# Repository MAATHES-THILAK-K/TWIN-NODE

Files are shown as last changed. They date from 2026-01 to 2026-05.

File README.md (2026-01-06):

## 📌 Project Overview

**TWIN-NODE** is a **two-node, ultra-low-power water level monitoring system** for overhead tanks.
It uses **ESP-NOW wireless communication**, requires **no internet**, and is optimized for **solar-powered outdoor operation**.

This project is **designed for manufacturable PCBs**, with all components chosen for reliability and low power.

---

## 🧩 System Architecture

| Node | Description |
| --- | --- |
| **NODE-1 (Outdoor Sensor Node)** | Measures water level using a waterproof ultrasonic sensor and transmits data wirelessly |
| **NODE-2 (Indoor Display Node)** | Receives water level data and alerts the user using LEDs and a buzzer |

---

## 🔧 NODE-1 – Outdoor Sensor Node

| Feature | Description |
| --- | --- |
| Controller | ESP-12F (ESP8266) |
| Sensor | SR04M / JSN-SR04T Waterproof Ultrasonic /HCSRO4|
| Power Source  | 18650 Li-ion Battery |
| Charging | Solar Panel + TP4056 |
| Regulation | RT9080-3.3 V LDO |
| Communication | ESP-NOW |
| Power Saving  | Deep Sleep + GPIO-controlled sensor power |
| Installation  | Weatherproof Enclosure |

---

## 🔋 Low-Power Design

| Technique | Purpose |
| --- | --- |
| Deep Sleep Mode | Minimizes battery consumption |
| GPIO-controlled Sensor Power | Cuts sensor standby current |
| LDO with low quiescent current | Efficient voltage regulation |
| ESP-NOW | Low-energy wireless communication |

---

## 📂 Repository Structure

| Folder | Purpose |
| --- | --- |
| `TWIN NODE V1.0/` | Stable, tested hardware revision |
| `TWIN NODE V2.0/` | Updated hardware revision (new features, improvements) |
| `Gerber/` | Manufacturing-ready files |
| `IMAGES/` | PCB renders and photos |
| `REPORT/` | ERC, DRC, design checks |
| `3D MODELS/` | Mechanical references |
| `LICENSE` | Open-source licensing information |
| `README.md` | Project overview and documentation |

---

## 🚀 Engineering Note

* Designed for **low-power operation**
* **Solar and battery-friendly**
* **Manufacturable PCB**
* Versioned structure makes it easy to track revisions

---

### 👤 Author

**MAATHES-THILAK-K (KMT)**
Embedded Systems | PCB Design | Robotics

---

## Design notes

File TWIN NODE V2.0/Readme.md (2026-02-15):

# TWIN NODE V2.0

### Low-Power Outdoor Water Level Sensor Node – Improved Design

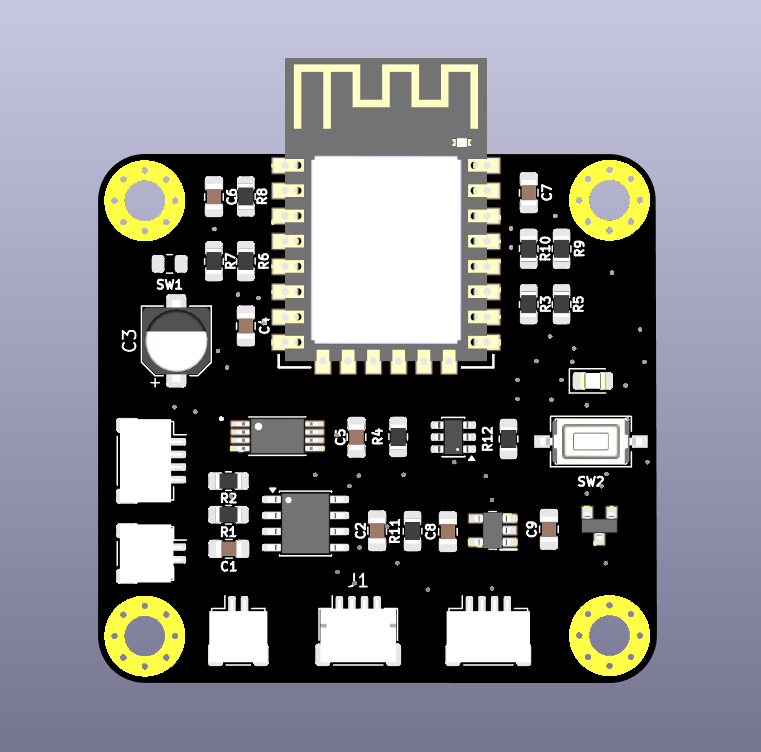
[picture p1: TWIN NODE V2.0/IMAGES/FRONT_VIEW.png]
TWIN NODE V2.0 Front View


---

## 📌 Overview

**TWIN NODE V2.0** is the **fabricated and tested hardware revision** of the low-power ESP-NOW water level monitoring system.
This version incorporates **real-world fabrication feedback**, improving reliability and simplifying the design for future revisions.

All components are sourced from [ROBU.IN](https://robu.in).

---

## ⚙️ Key Updates from V1.0

* **Mounting holes:** Increased from 3 to **4** for better casing support
* **I2C expanders:** Removed, no longer required
* **Programming & power connections:** Female headers replaced with **JST connectors**
* **Component placement:** Fully optimized for **aesthetic and practical routing**
* **PCB traces:** Increased width to support **longer interconnections**
* **PCB size:** ~45 × 45 mm
* **DRC & ERC:** Fully verified
* **Fabricated & powered ON successfully**

---

## 🛠️ Fabrication Feedback & Design Correction (Important)

During physical testing of the fabricated PCB, the following observation was made:

### ❌ Unnecessary Pull-Up Resistors Identified

* **GPIO0 (BOOT)** – 10 kΩ resistor **not required**
* **RST (RESET)** – 10 kΩ resistor **not required**

These resistors were found to be **redundant** and **can be safely removed** in future PCB revisions.

### ✅ Reason

* ESP8266 12K pull-ups are sufficient for:

  * Normal boot operation
  * Reliable reset behavior
* External 10 kΩ resistors on **GPIO0** and **RST**:

  * Do **not improve stability**
  * Increase component count unnecessarily
  * Slightly complicate routing and assembly

➡️ **Action for next revision:**
Remove the 10 kΩ pull-up resistors on **GPIO0 (BOOT)** and **RST**.

---

## 🔧 Design Notes

* Designed for **battery + solar operation**
* Optimized for **low power outdoor deployment**
* ESP-NOW based communication (no Wi-Fi AP dependency)
* Layout finalized with **manufacturability in mind**
* Suitable for **field deployment and enclosure mounting**

---

## 📦 Project Status

✔ PCB fabricated
✔ Power-up verified
✔ Boot & reset behavior validated
✔ Design improvement identified for next revision

---

### 👤 Author

**MAATHES-THILAK-K (KMT)**
Embedded Systems | PCB Design | Robotics

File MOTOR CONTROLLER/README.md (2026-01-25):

# ⚙️ TWIN-NODE – Motor Controller
## Overview

The **TWIN-NODE Motor Controller** is a compact wireless motor control module designed to work with the TWIN-NODE water level monitoring system.
It enables **remote ON/OFF control of a water pump** using **ESP-NOW**, without internet connectivity.

---
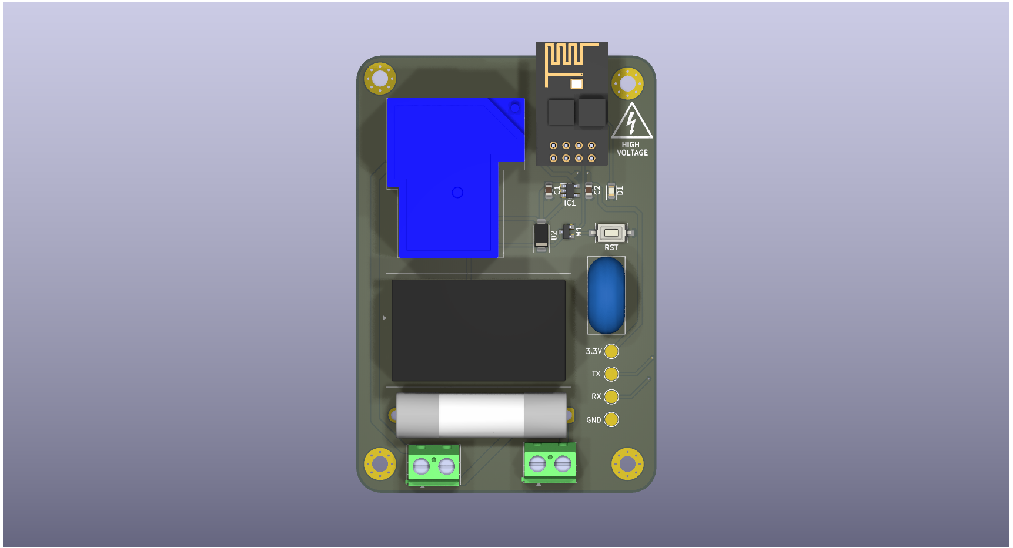
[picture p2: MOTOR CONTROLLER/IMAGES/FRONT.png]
Motor Controller PCB

---

## Key Features

* ESP-01 (ESP8266) based controller
* Wireless control using ESP-NOW
* Relay-based motor switching
* Electrical isolation between control and load
* Manufacturable PCB design

---

## Hardware Summary

| Item | Description |
| --- | --- |
| MCU | ESP-01 (ESP8266) |
| Communication | ESP-NOW |
| Motor Control | Relay |
| PCB Files | KiCad + Gerber |
| Application | Water pump control |

---

## Repository Contents

* Gerber files for manufacturing
* KiCad schematic & PCB
* 3D models and images
* Design reports (ERC/DRC)

---

## Author

**MAATHES-THILAK-K (KMT)**
Embedded Systems | PCB Design | Robotics

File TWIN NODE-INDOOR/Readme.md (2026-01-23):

# TWIN-NODE – Indoor Node

## Overview

The **Indoor Node** is a **battery-powered, ultra-low-power receiver and alert unit** for the TWIN-NODE water level monitoring system.
It receives water level data from the outdoor sensor node using **ESP-NOW** and provides **local LED and buzzer alerts**, without internet or Wi-Fi infrastructure.

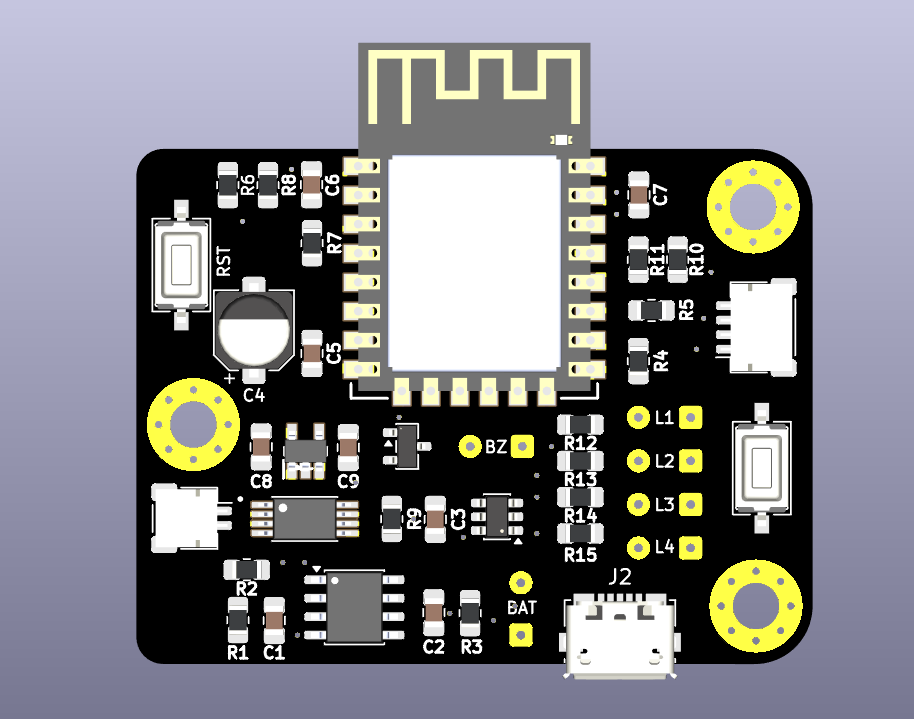
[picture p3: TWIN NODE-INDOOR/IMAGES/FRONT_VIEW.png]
Indoor Node Front View


---

## Key Features

* ESP-NOW wireless communication
* Battery-powered operation
* Ultra-low-power design
* LED level indication
* Buzzer alert for critical levels
* No internet, no router, no cloud

---

## Hardware Summary

| Item | Specification |
| --- | --- |
| MCU | ESP-12F (ESP8266) |
| Communication | ESP-NOW |
| Indicators | LEDs |
| Alert | Buzzer |
| Power Source  | Battery |
| Design Tool | KiCad |

---

## Power Design

* Deep sleep enabled
* Wake on ESP-NOW receive
* Minimal standby current
* Optimized for long-term battery life

---

## Repository Contents

| Path | Description |
| --- | --- |
| `GERBER/` | Manufacturing files |
| `IMAGES/` | PCB images |
| `REPORT/` | ERC / DRC |
| `3D MODELS/` | Mechanical models |
| `TWIN_NODE2.kicad_*` | Schematic & PCB |

---

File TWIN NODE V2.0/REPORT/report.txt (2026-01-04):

Plotted to '/home/kmt-universe/Desktop/TWIN_NODE/Gerber/TWIN_NODE-F_Cu.gbr'.
Plotted to '/home/kmt-universe/Desktop/TWIN_NODE/Gerber/TWIN_NODE-B_Cu.gbr'.
Plotted to '/home/kmt-universe/Desktop/TWIN_NODE/Gerber/TWIN_NODE-F_Paste.gbr'.
Plotted to '/home/kmt-universe/Desktop/TWIN_NODE/Gerber/TWIN_NODE-B_Paste.gbr'.
Plotted to '/home/kmt-universe/Desktop/TWIN_NODE/Gerber/TWIN_NODE-F_Silkscreen.gbr'.
Plotted to '/home/kmt-universe/Desktop/TWIN_NODE/Gerber/TWIN_NODE-B_Silkscreen.gbr'.
Plotted to '/home/kmt-universe/Desktop/TWIN_NODE/Gerber/TWIN_NODE-F_Mask.gbr'.
Plotted to '/home/kmt-universe/Desktop/TWIN_NODE/Gerber/TWIN_NODE-B_Mask.gbr'.
Plotted to '/home/kmt-universe/Desktop/TWIN_NODE/Gerber/TWIN_NODE-Edge_Cuts.gbr'.
Created Gerber job file '/home/kmt-universe/Desktop/TWIN_NODE/Gerber/TWIN_NODE-job.gbrjob'.
Info: Done.
Info: Done.

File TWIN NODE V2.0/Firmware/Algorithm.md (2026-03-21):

# 🌊 Smart Water Tank Monitoring System (ESP8266 + ESP-NOW)

## 📌 Overview

This project implements an **ultra-low-power outdoor water level monitoring system** using an ESP-12F (ESP8266) and ultrasonic sensing. The system communicates with an indoor node via **ESP-NOW**, ensuring efficient, connectionless data transfer.

The design prioritizes:

* 🔋 Ultra-low power consumption (solar + Li-ion)
* ⚡ Event-driven communication
* 📡 Reliable short-range wireless communication
* 🧠 Intelligent state-based operation

---

## 🏗️ System Architecture

### 🌿 Outdoor Node (Sensor Unit)

* ESP-12F (ESP8266)
* Ultrasonic sensor (power-gated via MOSFET)
* Solar + Li-ion powered
* Operates mostly in **deep sleep**

### 🏠 Indoor Node (User Interface)

* ESP8266 (ESP-NOW receiver)
* 4 LEDs (water level indication)
* Buzzer (alerts)
* Optional mobile connectivity

---

## 🔄 System Workflow

### 🌿 Outdoor Node (State Machine)

---

### 🔹 LOW POWER MODE

```text
[Deep Sleep]

↓ Wake (every 5 minutes)

Power ON ultrasonic
Wait 50 ms stabilization

Take 3 readings → Apply median filter
Power OFF ultrasonic

IF |current_distance - last_sent| < delta_threshold:
    → Return to deep sleep (5 min)

ELSE:
    Send data via ESP-NOW

    Wait 100 ms for ACK

    IF ACK received:
        last_sent = current_distance
        Reset failure counter
        Switch to ACTIVE MODE

    ELSE:
        Retry (max 2 times)
        → Return to deep sleep (5 min)
```

---

### ⚡ ACTIVE MODE

```text
Wake every 1–2 minutes

Measure distance (filtered)

IF |current_distance - last_sent| ≥ delta_threshold:
    Send data → Wait for ACK

    IF ACK received:
        Update last_sent
        Reset failure counter

    ELSE:
        Increment failure counter

IF failure counter ≥ 3:
    Switch to LOW POWER MODE

Return to deep sleep (1–2 min)
```

---

## 🏠 Indoor Node Logic

```text
Always listening (ESP-NOW)

On receiving data:
    Send ACK immediately
    Store received distance
    Update LED indicators
    Trigger buzzer (only if critical)

Optional:
    Send data to mobile application
```

---

## 📊 Water Level Indication

Water level is computed as:

```text
Level (%) = (Tank Height - Measured Distance) / Tank Height
```

| Level (%) | Indicator |
| --- | --- |
| 0–25% | LED 1 |
| 25–50% | LED 2 |
| 50–75% | LED 3 |
| 75–100% | LED 4 |

---

## 🔊 Buzzer Logic

The buzzer is triggered only when:

* ✅ Tank becomes FULL
* ⚠️ Sudden drop in water level (optional)

Avoid continuous alerts to improve user experience.

---

## 🧪 Sensor Filtering

To improve accuracy in outdoor conditions:

* Take **3 consecutive readings**
* Apply **median filtering**
* Reject noise and outliers

---

## 📡 Communication Protocol

### Data Packet (Outdoor → Indoor)

```c
struct DataPacket {
  uint16_t distance;
  uint8_t state;
  uint8_t battery; // optional
};
```

### ACK Packet (Indoor → Outdoor)

```c
struct AckPacket {
  uint8_t status; // 1 = received
};
```

---

## ⚡ Power Optimization Techniques

* Deep sleep between operations
* Sensor power gating via MOSFET
* Short ESP-NOW transmission bursts
* No continuous listening on outdoor node
* Event-driven communication

---

## 🔋 Power Profile

| Mode | Current Consumption |
| --- | --- |
| Deep Sleep | ~20–70 µA |
| Active | ~120 mA (short burst) |

---

## 🚨 Fail-Safe Mechanisms

| Condition | System Behavior |
| --- | --- |
| Indoor node OFF | Retry → fallback to LOW POWER MODE |
| Communication failure | Retry (max 2 times) |
| No ACK in ACTIVE MODE | Return to LOW POWER MODE |
| Sensor noise | Median filtering applied |

---

## 🚀 Future Improvements

* 🔋 Battery-aware adaptive sleep intervals
* 📶 Mobile app integration
* ☁️ Cloud logging
* 📉 Data history visualization
* 🧠 Predictive water usage analytics

---

## 🎯 Key Design Goals Achieved

* ✅ Ultra-low power outdoor node
* ✅ Reliable wireless communication
* ✅ Event-driven updates
* ✅ Scalable architecture
* ✅ User-friendly indoor interface

---

## 🙌 Author

Developed by **MAATHES THILAK K**
IInd year (4th semester)
March 22 2.22am 
---

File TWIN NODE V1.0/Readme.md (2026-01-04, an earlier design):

# TWIN NODE V1.0

### Low-Power Outdoor Water Level Sensor Node

---

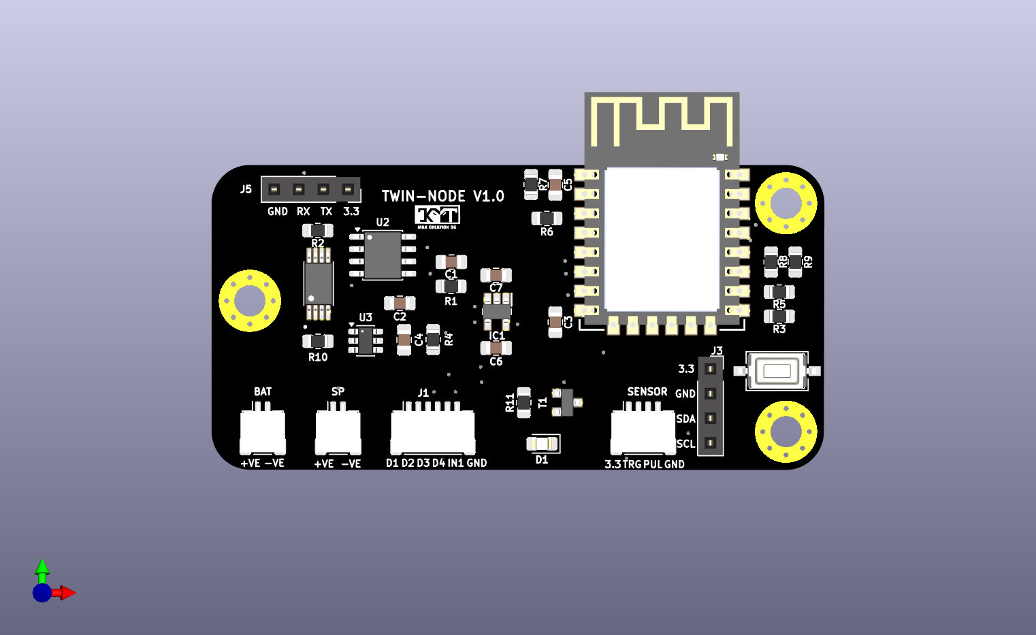
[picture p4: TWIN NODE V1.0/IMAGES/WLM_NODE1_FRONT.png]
TWIN NODE V1.0 Front View


## 📌 Overview

**TWIN NODE V1.0** is the **first hardware version** of a low-power, ESP-NOW-based water level monitoring system.
It is **designed for learning and prototyping**, with all components sourced from [ROBU.IN](https://robu.in).

---

## ⚙️ Features

* **ESP-12F (ESP8266)** controller
* **Waterproof ultrasonic sensor** for water level measurement
* **Female headers** for programming and I2C expanders
* **SCL & SDA I2C lines** accessible for future expansion
* **Three mounting holes** for secure installation
* PCB size: **~65 × 35 mm**
* Component placement: Functional but **aesthetic may be rough (good for first-time design)**
* **DRC & ERC verified**, footprints selected for manufacturability

---

## 🔧 Notes

* Ready for **battery + solar operation**
* Ideal for testing ESP-NOW wireless communication
* Serves as **foundation for TWIN NODE V2.0**

---

### 👤 Author

**MAATHES-THILAK-K (KMT)**
Embedded Systems | PCB Design | Robotics

---

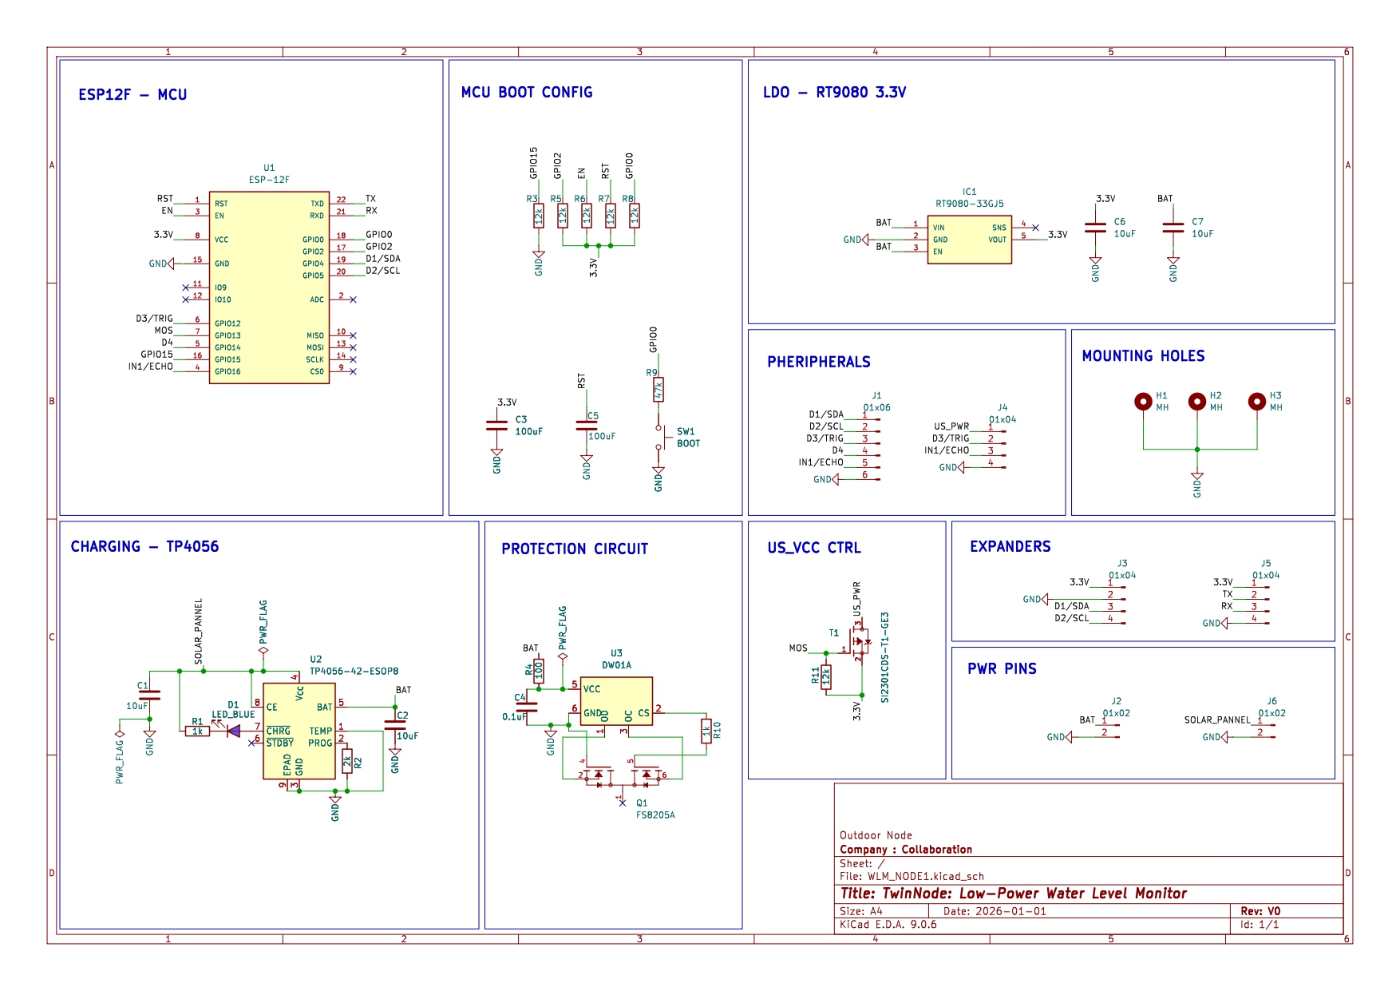
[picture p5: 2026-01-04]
TWIN NODE V2.0/IMAGES/TWIN_NODE_page-0001.jpg

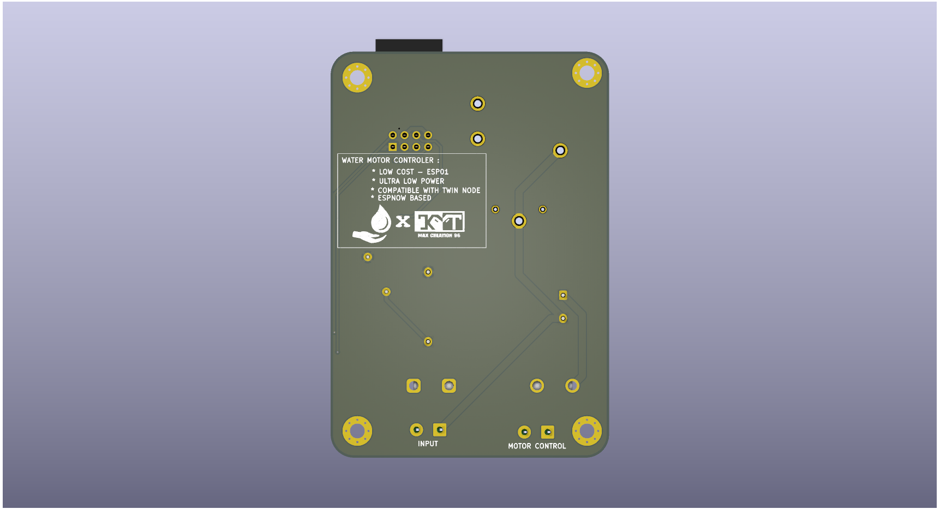
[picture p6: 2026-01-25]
MOTOR CONTROLLER/IMAGES/BACK.png

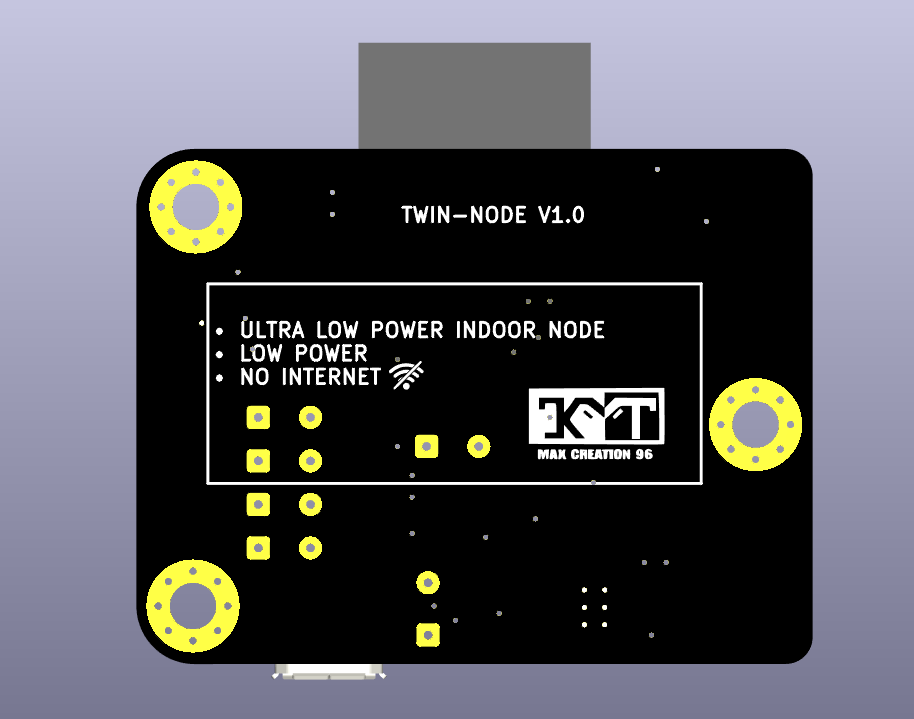
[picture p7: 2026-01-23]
TWIN NODE-INDOOR/IMAGES/BACK_VIEW.png

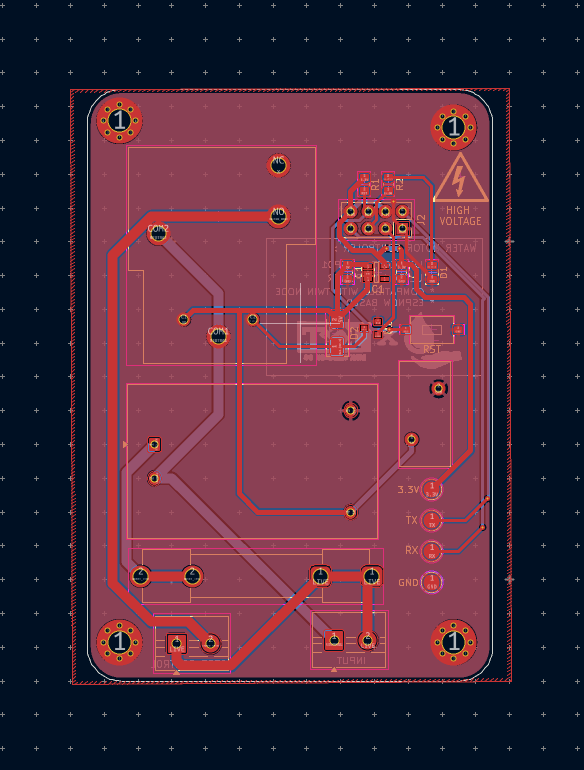
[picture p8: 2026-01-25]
MOTOR CONTROLLER/IMAGES/LAYOUT_1.png

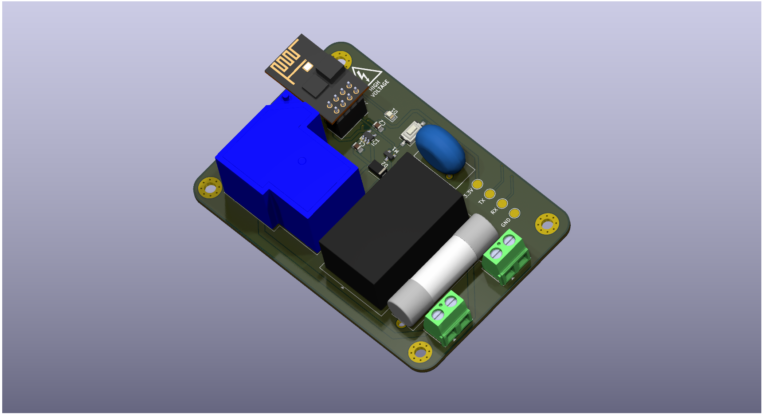
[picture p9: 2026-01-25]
MOTOR CONTROLLER/IMAGES/ISOMETRIC.png

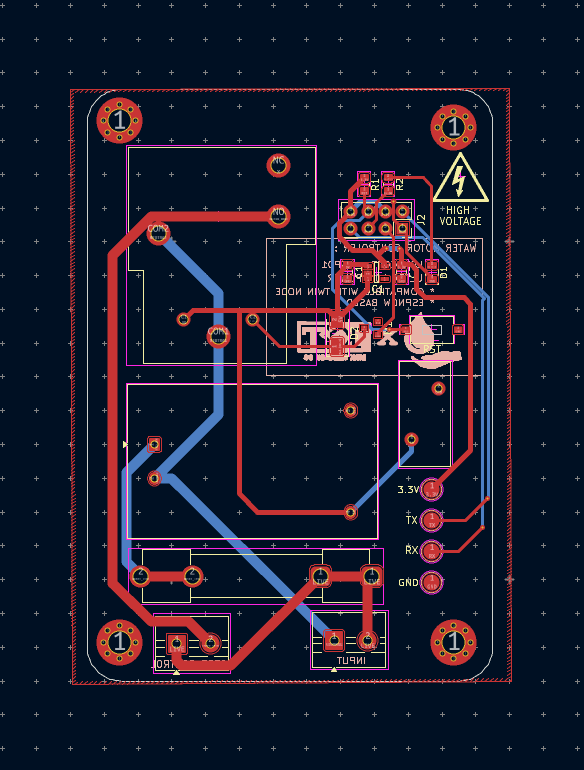
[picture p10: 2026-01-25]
MOTOR CONTROLLER/IMAGES/LAYOUT_2.png

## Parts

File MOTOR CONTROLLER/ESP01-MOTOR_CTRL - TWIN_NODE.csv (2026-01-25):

Reference | Qty | Value | DNP | Exclude from BOM | Exclude from Board | Footprint | Datasheet
C1,C2 | 2 | 10uF |  |  |  | Capacitor_SMD:C_0805_2012Metric_Pad1.18x1.45mm_HandSolder | ~
D1 | 1 | LED |  |  |  | LED_SMD:LED_0805_2012Metric_Pad1.15x1.40mm_HandSolder | ~
D2 | 1 | SS12 |  |  |  | Diode_SMD:D_SMA | https://www.vishay.com/docs/88746/ss12.pdf
F1 | 1 | 250V@500mA |  |  |  | Fuse:Fuseholder_Clip-6.3x32mm_Littelfuse_102_122_Inline_P34.21x7.62mm_D1.98mm_Horizontal | ~
H1,H2,H3,H4 | 4 | MH |  | Excluded from BOM |  | MountingHole:MountingHole_3.2mm_M3_Pad_Via | ~
IC1 | 1 | RT9080-33GJ5 |  |  |  | RT9080-33GJ5:SOT94P280X100-5N
J1 | 1 | MOTOR |  |  |  | TerminalBlock:TerminalBlock_MaiXu_MX126-5.0-02P_1x02_P5.00mm | ~
J2 | 1 | 02X04 |  |  |  | Connector_PinSocket_2.54mm:PinSocket_2x04_P2.54mm_Vertical | ~
J3 | 1 | INPUT |  |  |  | TerminalBlock:TerminalBlock_MaiXu_MX126-5.0-02P_1x02_P5.00mm | ~
K1 | 1 | SLA-5VDC-SL-C |  |  |  | SLA-12VDC-SL-C:RELAY_SLA-12VDC-SL-C
M1 | 1 | SI2300 |  |  |  | SI2301CDS-T1-GE3:SOT-23
PS1 | 1 | HLK-PM01 |  |  |  | Converter_ACDC:Converter_ACDC_Hi-Link_HLK-PMxx | https://h.hlktech.com/download/ACDC%E7%94%B5%E6%BA%90%E6%A8%A1%E5%9D%973W%E7%B3%BB%E5%88%97/1/%E6%B5%B7%E5%87%8C%E7%A7%913W%E7%B3%BB%E5%88%97%E7%94%B5%E6%BA%9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
R1 | 1 | 10K |  |  |  | Resistor_SMD:R_0805_2012Metric_Pad1.20x1.40mm_HandSolder | ~
R2 | 1 | 1K |  |  |  | Resistor_SMD:R_0805_2012Metric_Pad1.20x1.40mm_HandSolder | ~
RV1 | 1 | 275V-14D |  |  |  | Varistor:RV_Disc_D15.5mm_W7.5mm_P7.5mm | ~
SW1 | 1 | SW_Push |  |  |  | Button_Switch_SMD:SW_Tactile_SPST_NO_Straight_CK_PTS636Sx25SMTRLFS | ~
TP1,TP2,TP3,TP4 | 4 | TestPoint |  |  |  | TestPoint:TestPoint_Pad_D2.5mm | ~

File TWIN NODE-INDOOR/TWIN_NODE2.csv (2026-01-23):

Reference | Qty | Value | DNP | Exclude from BOM | Exclude from Board | Footprint | Datasheet
C1,C2,C5,C8,C9 | 5 | 10uF |  |  |  | Capacitor_SMD:C_0805_2012Metric_Pad1.18x1.45mm_HandSolder | ~
C3 | 1 | 0.1uF |  |  |  | Capacitor_SMD:C_0805_2012Metric_Pad1.18x1.45mm_HandSolder | ~
C4 | 1 | 100uF |  |  |  | Capacitor_SMD:CP_Elec_5x5.3 | ~
C6,C7 | 2 | 100nF |  |  |  | Capacitor_SMD:C_0805_2012Metric_Pad1.18x1.45mm_HandSolder | ~
D1 | 1 | LED_BLUE |  |  |  | Connector_Wire:SolderWire-0.1sqmm_1x02_P3.6mm_D0.4mm_OD1mm | ~
D2,D3,D4,D5 | 4 | LED |  |  |  | Connector_Wire:SolderWire-0.1sqmm_1x02_P3.6mm_D0.4mm_OD1mm | ~
H1,H2,H3 | 3 | MH |  | Excluded from BOM |  | MountingHole:MountingHole_3.2mm_M3_Pad_Via | ~
IC1 | 1 | RT9080-33GJ5 |  |  |  | RT9080-33GJ5:SOT94P280X100-5N
J1 | 1 | 01x02 |  |  |  | Connector_Wire:SolderWire-0.1sqmm_1x02_P3.6mm_D0.4mm_OD1mm | ~
J2 | 1 | USB_B_Micro |  |  |  | Connector_USB:USB_Micro-B_Molex_47346-0001 | ~
J3 | 1 | 01x02 |  |  |  | Connector_JST:JST_SH_SM02B-SRSS-TB_1x02-1MP_P1.00mm_Horizontal | ~
J4 | 1 | 01x04 |  |  |  | Connector_JST:JST_SH_SM04B-SRSS-TB_1x04-1MP_P1.00mm_Horizontal | ~
Q1 | 1 | FS8205A |  |  |  | FS8205A:SOP65P640X120-8N
Q2 | 1 | BSS138 |  |  |  | Package_TO_SOT_SMD:SOT-23 | https://www.onsemi.com/pub/Collateral/BSS138-D.PDF
R1,R9 | 2 | 1k |  |  |  | Resistor_SMD:R_0805_2012Metric_Pad1.20x1.40mm_HandSolder | ~
R2 | 1 | 2k |  |  |  | Resistor_SMD:R_0805_2012Metric_Pad1.20x1.40mm_HandSolder | ~
R3 | 1 | 100 |  |  |  | Resistor_SMD:R_0805_2012Metric_Pad1.20x1.40mm_HandSolder | ~
R4,R5,R7,R8,R10 | 5 | 12k |  |  |  | Resistor_SMD:R_0805_2012Metric_Pad1.20x1.40mm_HandSolder | ~
R6,R11 | 2 | 10k |  |  |  | Resistor_SMD:R_0805_2012Metric_Pad1.20x1.40mm_HandSolder | ~
R12,R13,R14,R15 | 4 | 330 |  |  |  | Resistor_SMD:R_0805_2012Metric_Pad1.20x1.40mm_HandSolder | ~
SW1 | 1 | RST |  |  |  | Button_Switch_SMD:SW_Tactile_SPST_NO_Straight_CK_PTS636Sx25SMTRLFS | ~
SW2 | 1 | BOOT |  |  |  | Button_Switch_SMD:SW_Tactile_SPST_NO_Straight_CK_PTS636Sx25SMTRLFS | ~
U1 | 1 | ESP-12F |  |  |  | ESP-12F:ESP-12F
U2 | 1 | TP4056-42-ESOP8 |  |  |  | Package_SO:SOIC-8-1EP_3.9x4.9mm_P1.27mm_EP2.41x3.3mm_ThermalVias | https://www.lcsc.com/datasheet/lcsc_datasheet_2410121619_TOPPOWER-Nanjing-Extension-Microelectronics-TP4056-42-ESOP8_C16581.pdf
U3 | 1 | DW01A |  |  |  | Package_TO_SOT_SMD:SOT-23-6 | https://hmsemi.com/downfile/DW01A.PDF

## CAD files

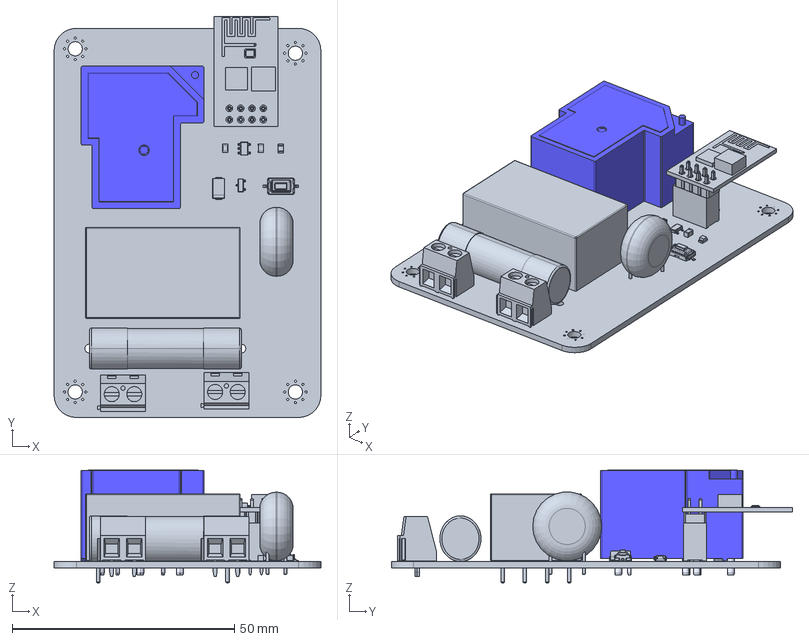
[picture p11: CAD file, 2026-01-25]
MOTOR CONTROLLER/3D MODEL/ESP01-MOTOR_CTRL - TWIN_NODE.step
60.0 x 90.2 x 25.3 mm
SLA-12VDC-SL-C_SLA-12VDC-SL-C
SI2300
D_SMA
R_0805_2012Metric x 2
282837-2--3DModel-STEP-269445 x 2
BUSSMANN PV Fuse 10x38mm
RV_Disc_D15.5mm_W7.5mm_P7.5mm
LED_0805_2012Metric
PinSocket_2x04_P2.54mm_Vertical
ESP-01
Converter_ACDC_Hi-Link_HLK-PMxx
SW_Tactile_SPST_NO_Straight_CK_PTS636Sx25SMTRLFS
C_0805_2012Metric x 2
RT9080-33GJ5
ESP01-MOTOR_CTRL - TWIN_NODE_PCB

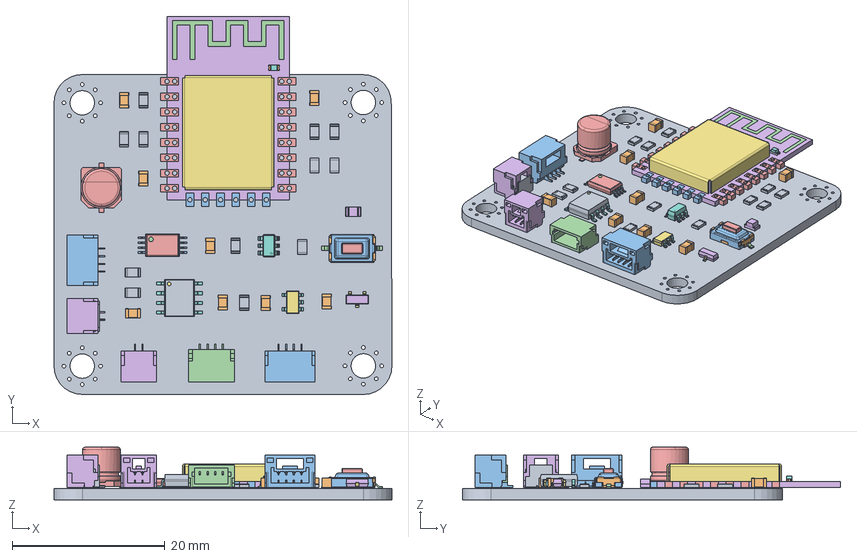
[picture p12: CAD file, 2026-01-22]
TWIN NODE V2.0/3D MODELS/TWIN_NODE.step
44.2 x 49.5 x 6.89 mm
R_0805_2012Metric x 12
C_0805_2012Metric x 8
FS8205A--3DModel-STEP-56544
JST_GH_SM02B-GHS-TB_1x02-1MP_P1.25mm_Horizontal x 2
TP4056
JST_GH_SM04B-GHS-TB_1x04-1MP_P1.25mm_Horizontal x 2
JST_SH_SM04B-SRSS-TB_1x04-1MP_P1.00mm_Horizontal
CP_Elec_5x5.3
LED_0805_2012Metric
ESP-12F
RT9080-33GJ5
JST_SH_SM02B-SRSS-TB_1x02-1MP_P1.00mm_Horizontal
SW_Tactile_SPST_NO_Straight_CK_PTS636Sx25SMTRLFS
SI2301CDS-T1-GE3
SOT-23-6
TWIN_NODE_PCB

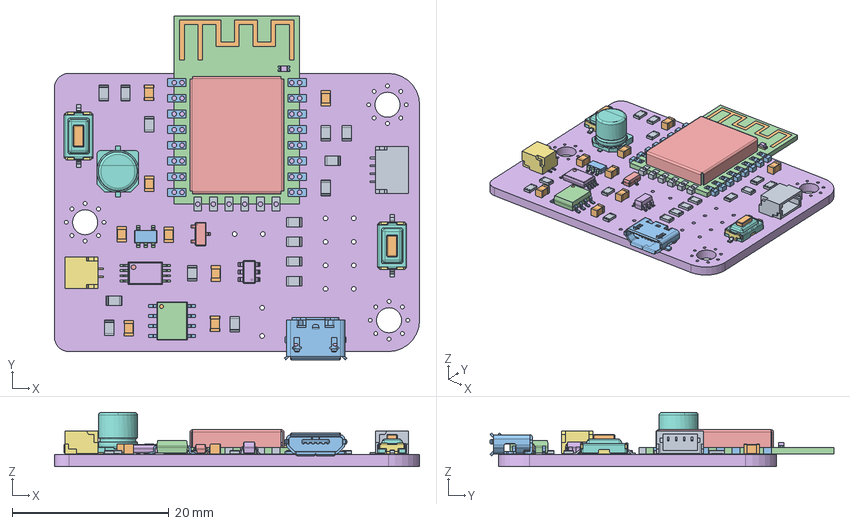
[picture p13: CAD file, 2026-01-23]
TWIN NODE-INDOOR/3D MODELS/TWIN_NODE2.step
46.6 x 43.9 x 6.89 mm
R_0805_2012Metric x 15
C_0805_2012Metric x 8
USB_Micro-B_Molex_47346-0001
FS8205A--3DModel-STEP-56544
SW_Tactile_SPST_NO_Straight_CK_PTS636Sx25SMTRLFS x 2
RT9080-33GJ5
ESP-12F
SOT-23
SOT-23-6
JST_SH_SM02B-SRSS-TB_1x02-1MP_P1.00mm_Horizontal
CP_Elec_5x5.3
JST_SH_SM04B-SRSS-TB_1x04-1MP_P1.00mm_Horizontal
TP4056
TWIN_NODE2_PCB

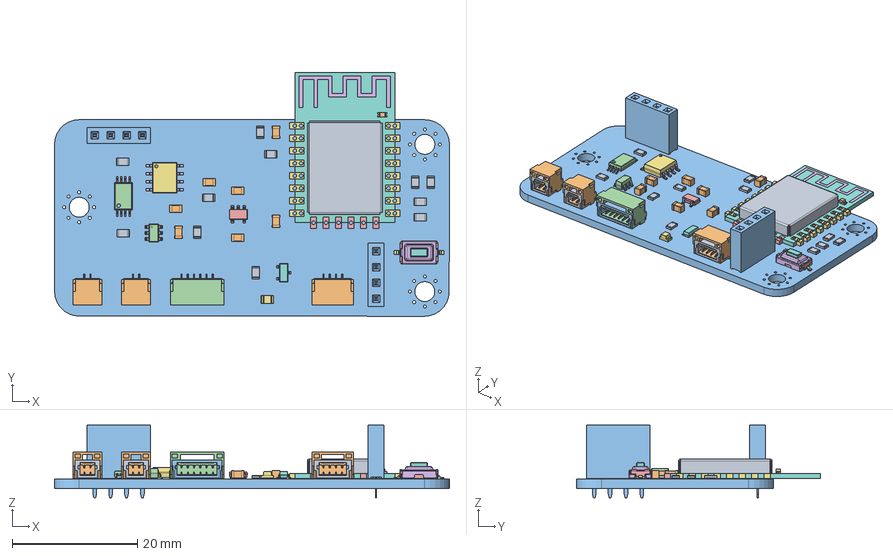
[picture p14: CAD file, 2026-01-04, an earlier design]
TWIN NODE V1.0/3D MODELS/WLM_NODE1.step
63.2 x 39.0 x 11.6 mm
R_0805_2012Metric x 11
C_0805_2012Metric x 7
JST_SH_SM06B-SRSS-TB_1x06-1MP_P1.00mm_Horizontal
JST_GH_SM06B-GHS-TB_1x06-1MP_P1.25mm_Horizontal
RT9080-33GJ5
LED_0805_2012Metric
SI2301CDS-T1-GE3
FS8205A--3DModel-STEP-56544
TP4056
JST_SH_SM02B-SRSS-TB_1x02-1MP_P1.00mm_Horizontal x 2
JST_GH_SM02B-GHS-TB_1x02-1MP_P1.25mm_Horizontal x 2
PinSocket_1x04_P2.54mm_Vertical x 2
SOT-23-6
SW_Tactile_SPST_NO_Straight_CK_PTS636Sx25SMTRLFS
ESP-12F
JST_SH_SM04B-SRSS-TB_1x04-1MP_P1.00mm_Horizontal
JST_GH_SM04B-GHS-TB_1x04-1MP_P1.25mm_Horizontal
WLM_NODE1_PCB

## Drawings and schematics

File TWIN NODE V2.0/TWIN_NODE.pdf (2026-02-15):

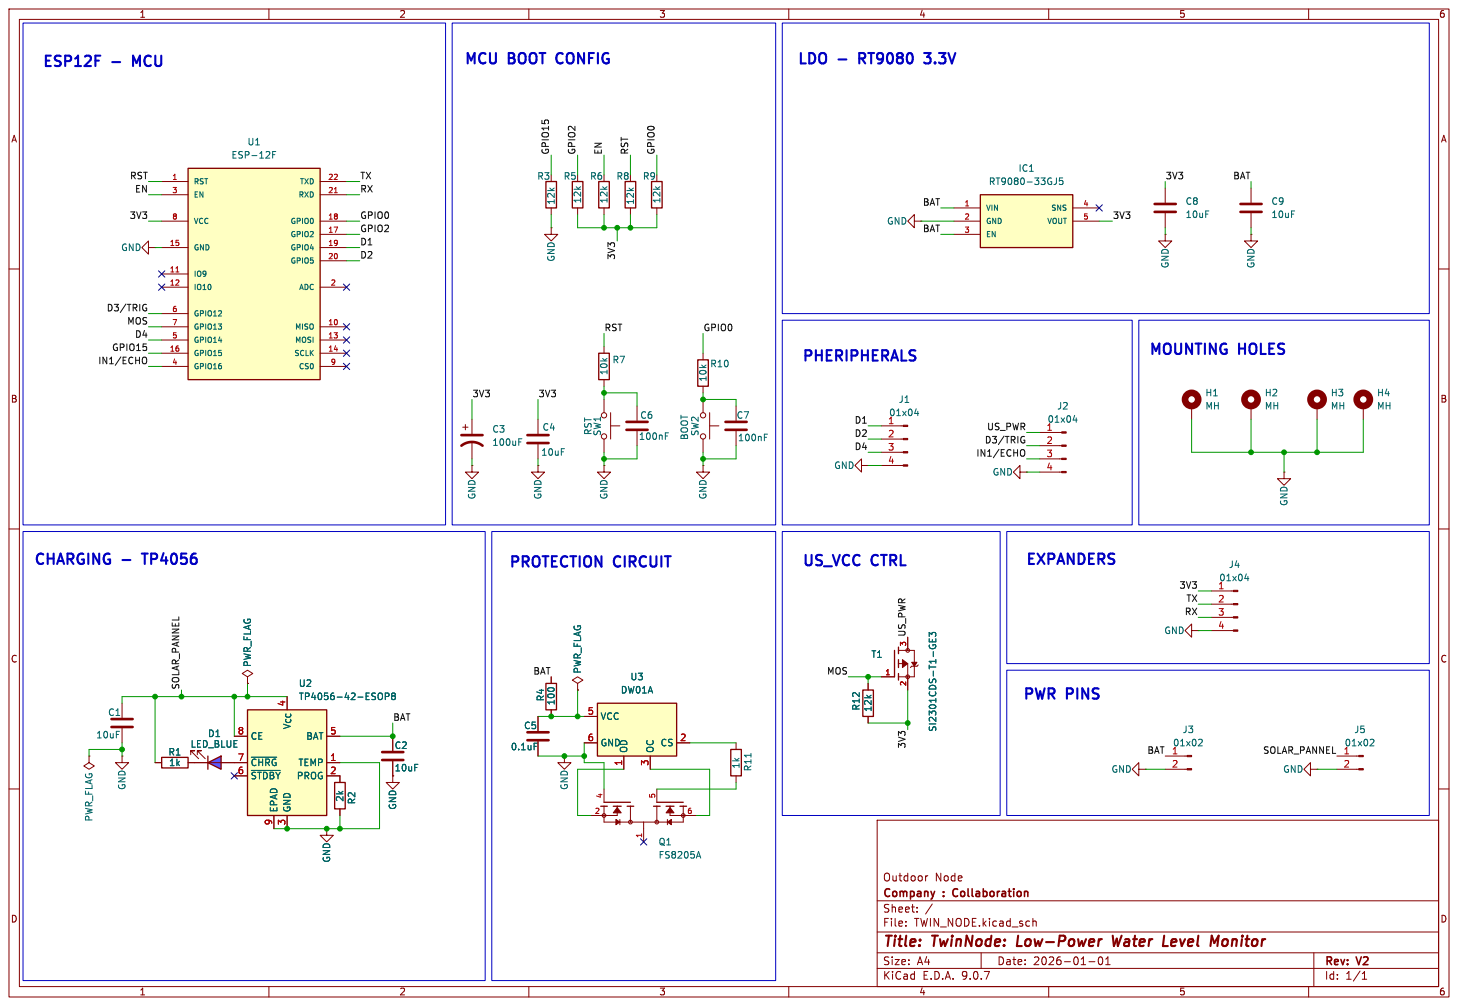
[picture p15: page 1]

3 BAT 5 TEMP 1 PROG 2 U2 TP4056-42-ESOP8 GND

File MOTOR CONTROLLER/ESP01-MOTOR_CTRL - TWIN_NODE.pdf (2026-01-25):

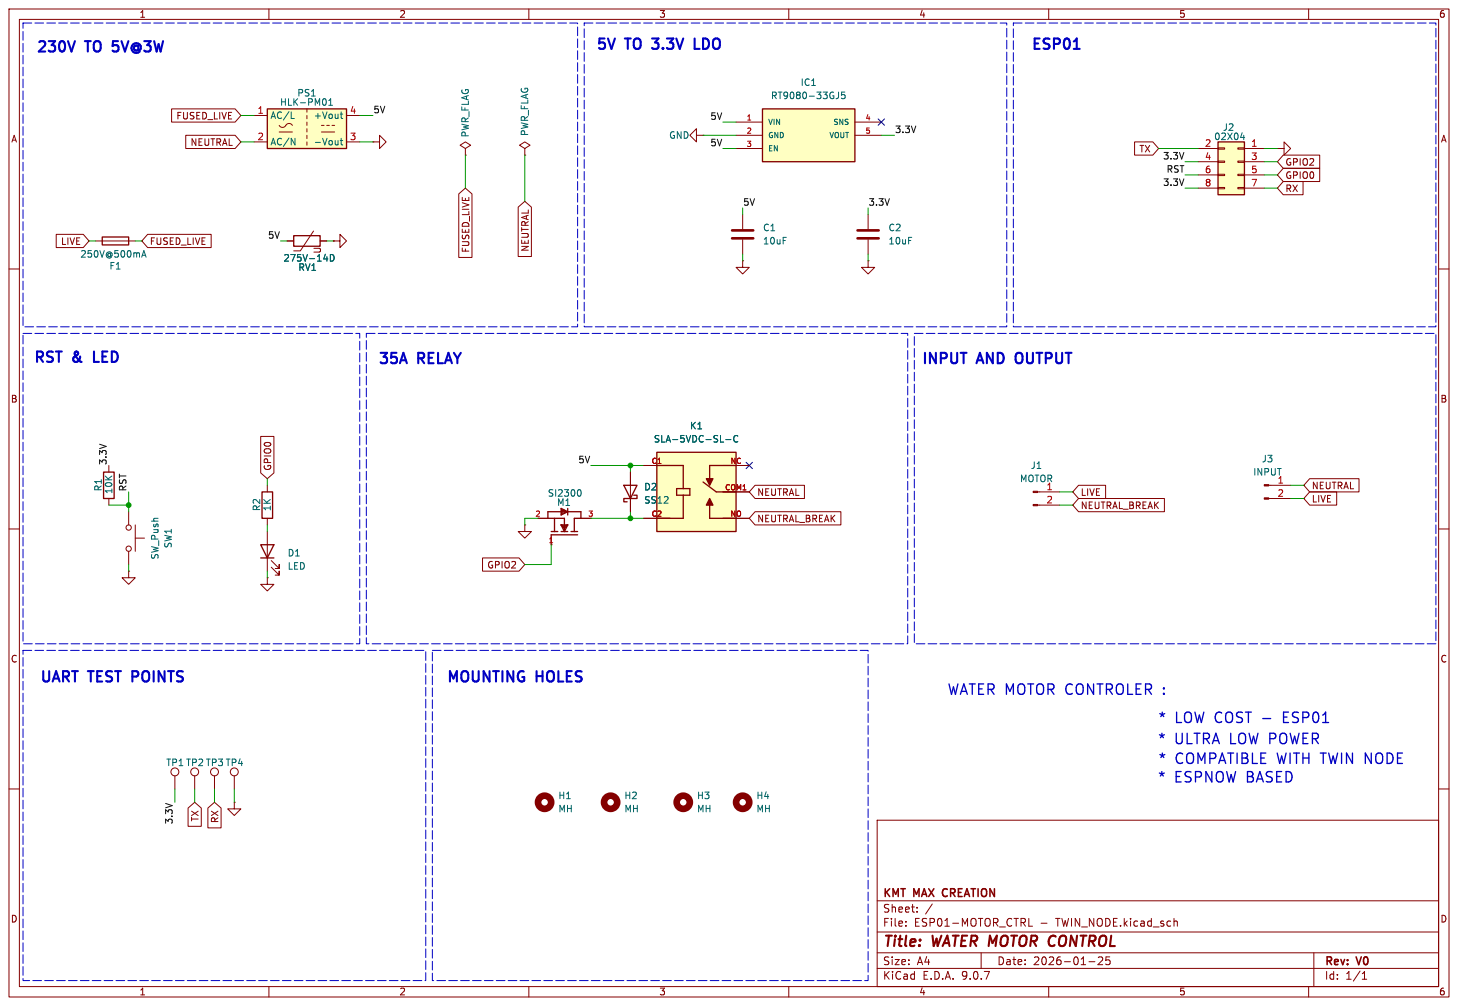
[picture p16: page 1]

Id: 1/1 Title: WATER MOTOR CONTROL

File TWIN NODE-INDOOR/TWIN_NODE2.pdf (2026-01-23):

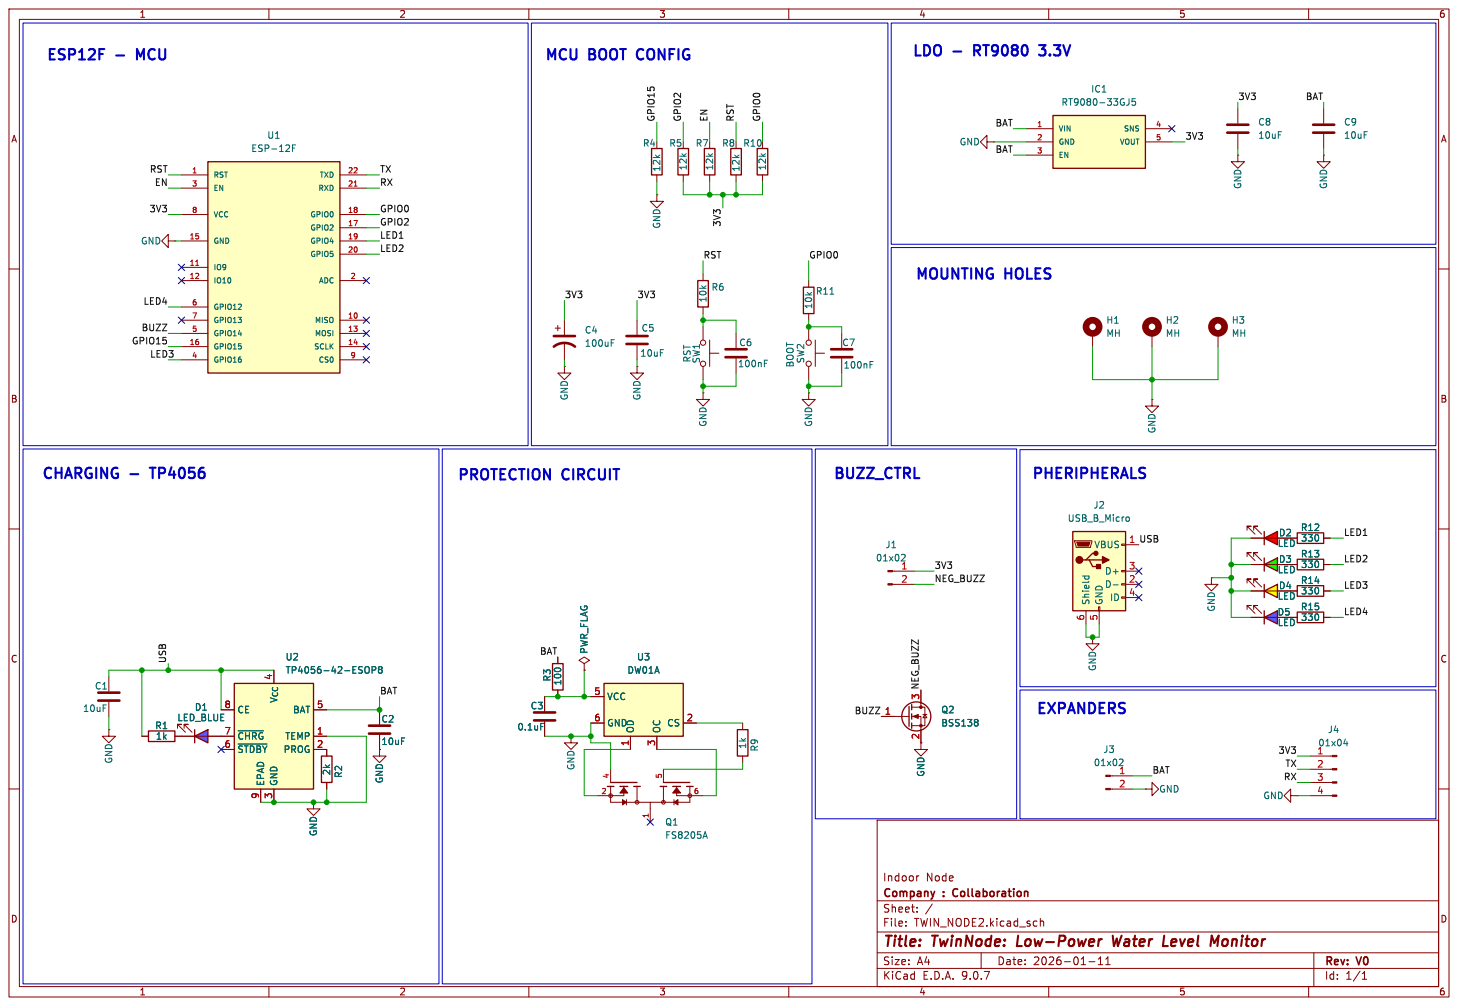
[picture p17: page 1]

3 BAT 5 TEMP 1 PROG 2 U2 TP4056-42-ESOP8 GND

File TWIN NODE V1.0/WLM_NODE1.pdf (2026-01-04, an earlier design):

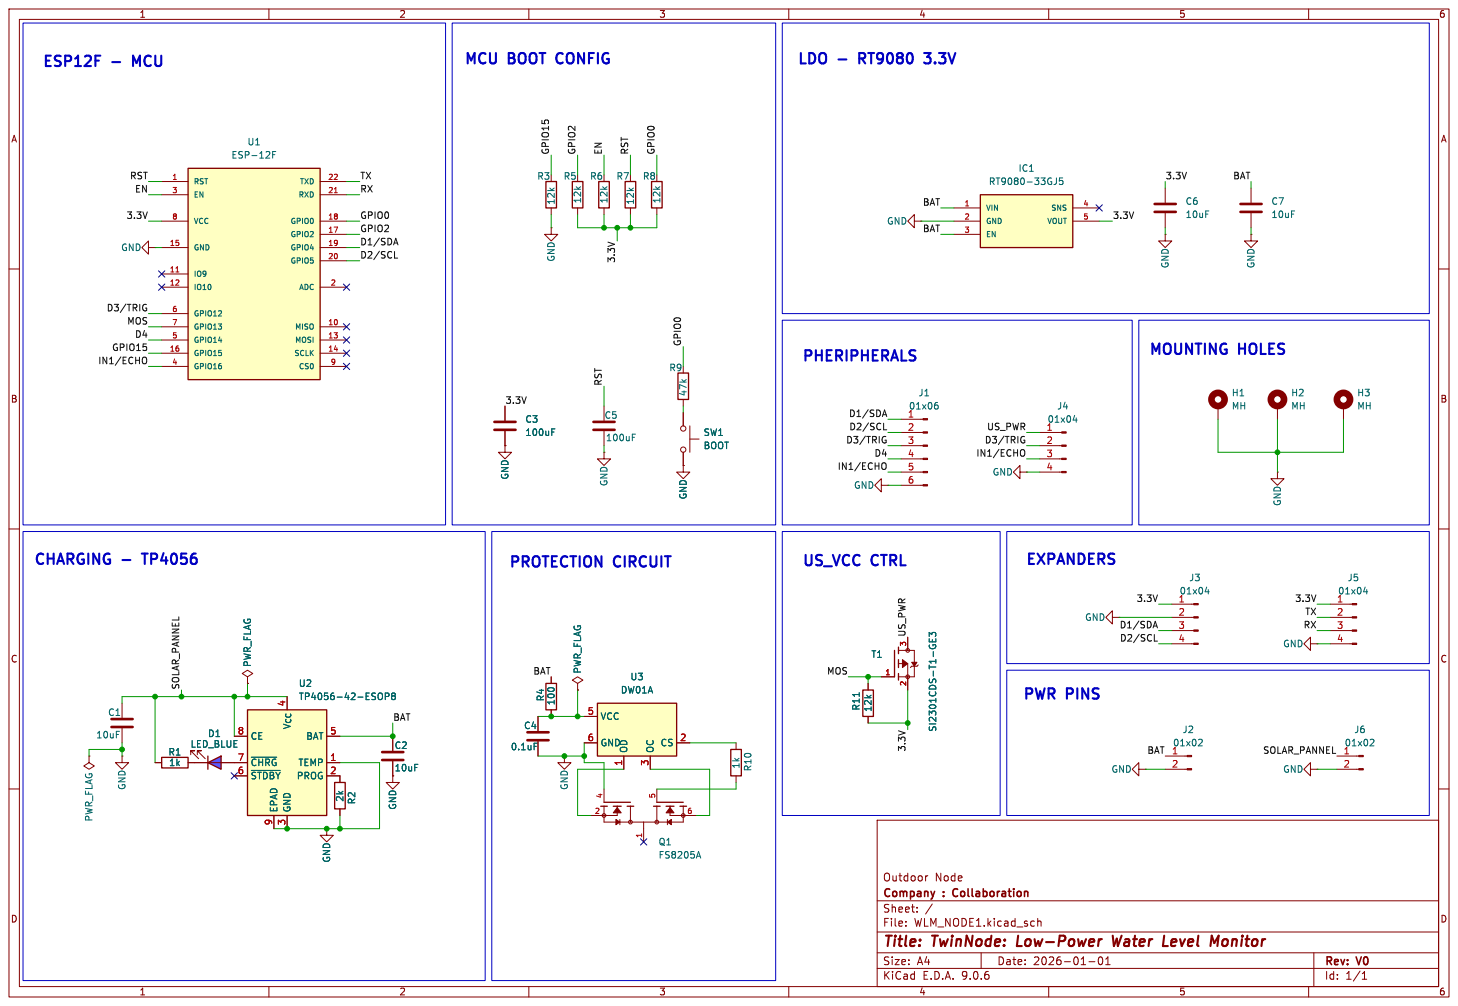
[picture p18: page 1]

01x02 GND GND GND R22k GND

3 BAT 5 TEMP 1 PROG 2GND R22k GND

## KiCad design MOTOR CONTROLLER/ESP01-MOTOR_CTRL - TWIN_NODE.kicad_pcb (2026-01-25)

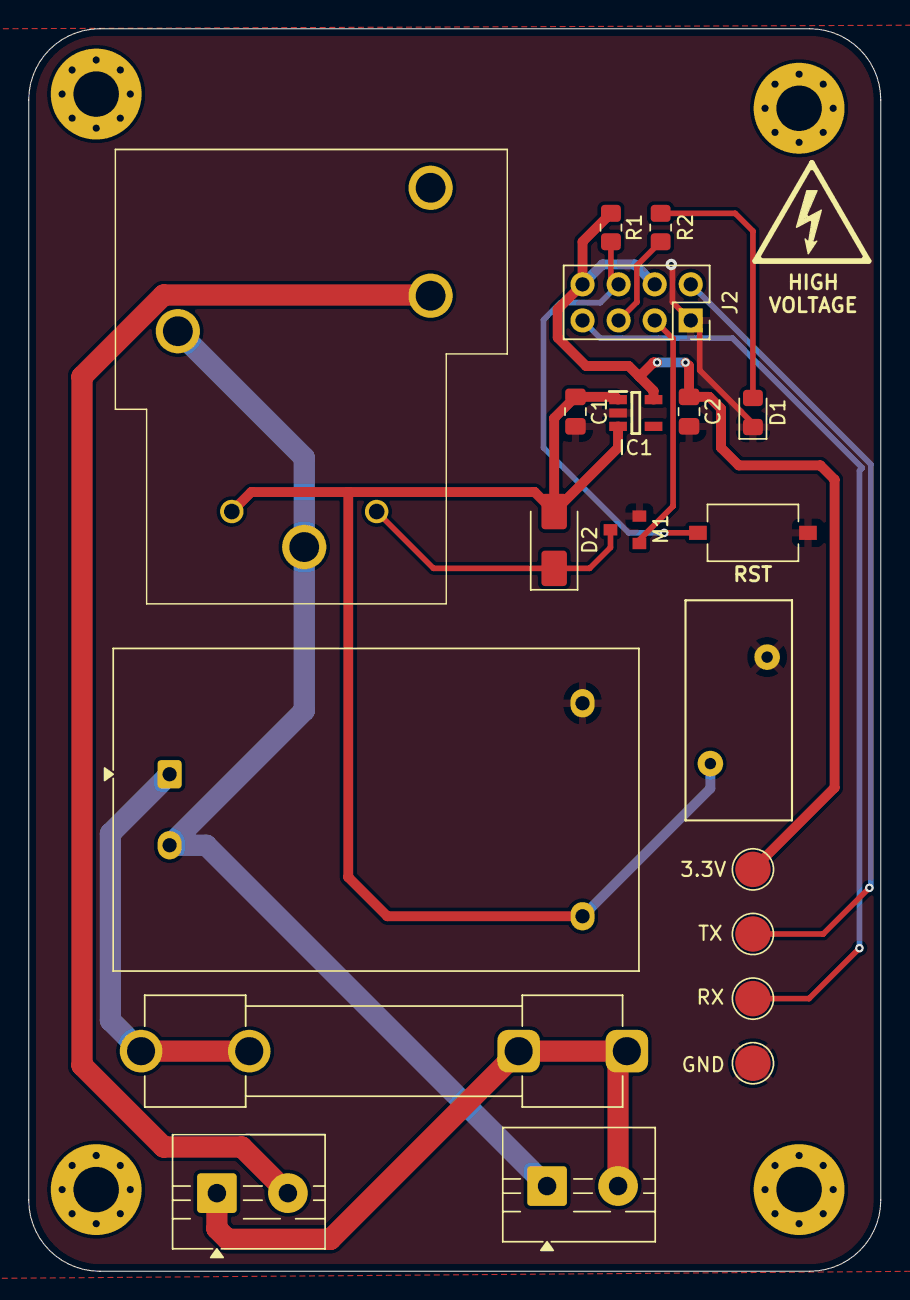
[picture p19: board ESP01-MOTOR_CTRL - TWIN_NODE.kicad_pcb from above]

Board: 2 copper layers, 60.0 x 87.5 mm, 24 parts (0 on the bottom side), 14 nets.

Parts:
3.3V: TestPoint; TestPoint_Pad_D2.5mm
C1, C2: 10uF; C_0805_2012Metric_Pad1.18x1.45mm_HandSolder
D1: LED; LED_0805_2012Metric_Pad1.15x1.40mm_HandSolder
D2: SS12; D_SMA
F1: 250V@500mA; Fuseholder_Clip-6.3x32mm_Littelfuse_102_122_Inline_P34.21x7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
GND: TestPoint; TestPoint_Pad_D2.5mm
H1, H2, H3, H4: MH; MountingHole_3.2mm_M3_Pad_Via
IC1: RT9080-33GJ5; SOT94P280X100-5N
J1: MOTOR; TerminalBlock_MaiXu_MX126-5.0-02P_1x02_P5.00mm
J2: 02X04; PinSocket_2x04_P2.54mm_Vertical
J3: INPUT; TerminalBlock_MaiXu_MX126-5.0-02P_1x02_P5.00mm
K1: SLA-5VDC-SL-C; RELAY_SLA-12VDC-SL-C
M1: SI2300; SOT-23
PS1: HLK-PM01; Converter_ACDC_Hi-Link_HLK-PMxx
R1: 10K; R_0805_2012Metric_Pad1.20x1.40mm_HandSolder
R2: 1K; R_0805_2012Metric_Pad1.20x1.40mm_HandSolder
RV1: 275V-14D; RV_Disc_D15.5mm_W7.5mm_P7.5mm
RX: TestPoint; TestPoint_Pad_D2.5mm
SW1: SW_Push; SW_Tactile_SPST_NO_Straight_CK_PTS636Sx25SMTRLFS
TX: TestPoint; TestPoint_Pad_D2.5mm

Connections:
/3.3V: 3.3V.1, C2.1, IC1.5 (VOUT), J2.4, J2.8, R1.1
/5V: C1.1, D2.2 (A), IC1.1 (VIN), IC1.3 (EN), K1.C1, PS1.4 (+Vout), RV1.1
/RST: J2.6, R1.2, SW1.1
FUSED_LIVE: F1.2, PS1.1 (AC/L)
GND: C1.2, C2.2, D1.1 (K), GND.1, IC1.2 (GND), J2.1, M1.2, PS1.3 (-Vout), RV1.2, SW1.2
GPIO0: J2.5, R2.1
GPIO2: J2.3, M1.1
LIVE: F1.1, J1.1, J3.2
NEUTRAL: J3.1, K1.COM1, K1.COM2, PS1.2 (AC/N)
NEUTRAL_BREAK: J1.2, K1.NO
unnamed: D1.2 (A), R2.2
unnamed: D2.1 (K), K1.C2, M1.3
RX: J2.7, RX.1
TX: J2.2, TX.1

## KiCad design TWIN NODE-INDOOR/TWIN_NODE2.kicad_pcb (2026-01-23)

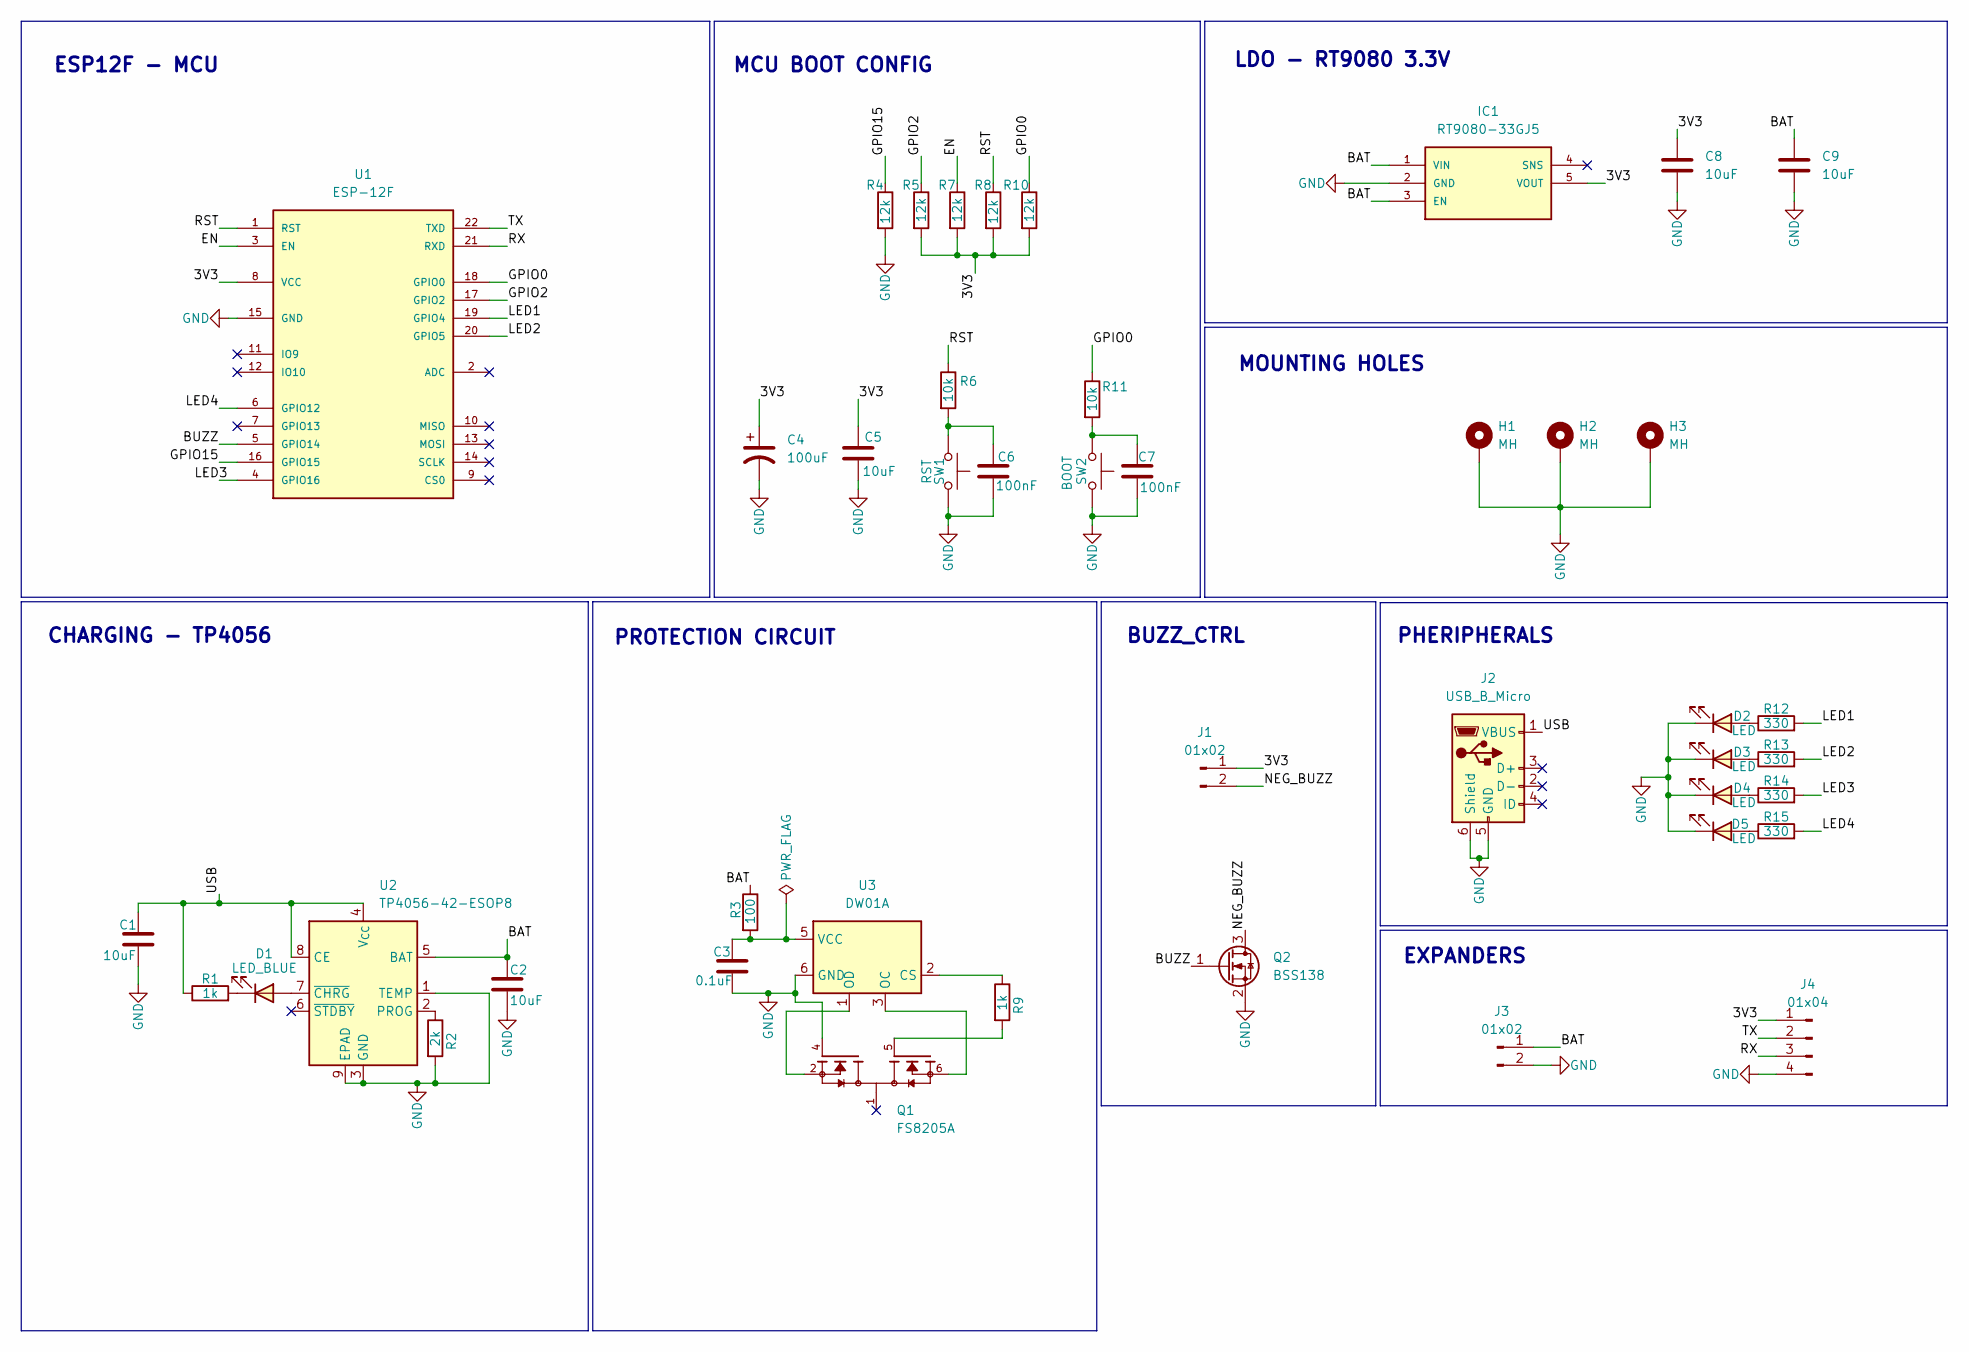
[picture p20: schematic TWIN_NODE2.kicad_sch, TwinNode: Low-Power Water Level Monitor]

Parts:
C1, C2, C5, C8, C9: 10uF; C_0805_2012Metric_Pad1.18x1.45mm_HandSolder
C3: 0.1uF; C_0805_2012Metric_Pad1.18x1.45mm_HandSolder
C4: 100uF; CP_Elec_5x5.3
C6, C7: 100nF; C_0805_2012Metric_Pad1.18x1.45mm_HandSolder
D1: LED_BLUE; SolderWire-0.1sqmm_1x02_P3.6mm_D0.4mm_OD1mm
D2, D3, D4, D5: LED; SolderWire-0.1sqmm_1x02_P3.6mm_D0.4mm_OD1mm
H1, H2, H3: MH; MountingHole_3.2mm_M3_Pad_Via
IC1: RT9080-33GJ5; SOT94P280X100-5N
J1: 01x02; SolderWire-0.1sqmm_1x02_P3.6mm_D0.4mm_OD1mm
J2: USB_B_Micro; USB_Micro-B_Molex_47346-0001
J3: 01x02; JST_SH_SM02B-SRSS-TB_1x02-1MP_P1.00mm_Horizontal
J4: 01x04; JST_SH_SM04B-SRSS-TB_1x04-1MP_P1.00mm_Horizontal
Q1: FS8205A; SOP65P640X120-8N; PARTREV 1.7
Q2: BSS138; SOT-23
R1, R9: 1k; R_0805_2012Metric_Pad1.20x1.40mm_HandSolder
R2: 2k; R_0805_2012Metric_Pad1.20x1.40mm_HandSolder
R3: 100; R_0805_2012Metric_Pad1.20x1.40mm_HandSolder
R4, R5, R7, R8, R10: 12k; R_0805_2012Metric_Pad1.20x1.40mm_HandSolder
R6, R11: 10k; R_0805_2012Metric_Pad1.20x1.40mm_HandSolder
R12, R13, R14, R15: 330; R_0805_2012Metric_Pad1.20x1.40mm_HandSolder
SW1: RST; SW_Tactile_SPST_NO_Straight_CK_PTS636Sx25SMTRLFS
SW2: BOOT; SW_Tactile_SPST_NO_Straight_CK_PTS636Sx25SMTRLFS
U1: ESP-12F
U2: TP4056-42-ESOP8; SOIC-8-1EP_3.9x4.9mm_P1.27mm_EP2.41x3.3mm_ThermalVias
U3: DW01A; SOT-23-6

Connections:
/3V3: C4.1, C5.1, C8.1, IC1.5 (VOUT), J1.1, J4.1, R5.2, R7.2, R8.2, R10.2, U1.8 (VCC)
/BAT: C2.1, C9.1, IC1.1 (VIN), IC1.3 (EN), J3.1, R3.1, U2.5 (BAT)
/BUZZ: Q2.1 (G), U1.5 (GPIO14)
/EN: R7.1, U1.3 (EN)
/GPIO0: R10.1, R11.1, U1.18 (GPIO0)
/GPIO2: R5.1, U1.17 (GPIO2)
/GPIO15: R4.1, U1.16 (GPIO15)
/LED1: R12.2, U1.19 (GPIO4)
/LED2: R13.2, U1.20 (GPIO5)
/LED3: R14.2, U1.4 (GPIO16)
/LED4: R15.2, U1.6 (GPIO12)
/NEG_BUZZ: J1.2, Q2.3 (D)
/RST: R6.1, R8.1, U1.1 (RST)
/RX: J4.3, U1.21 (RXD)
/TX: J4.2, U1.22 (TXD)
/USB: C1.1, J2.1 (VBUS), R1.1, U2.4 (V_{CC}), U2.8 (CE)
GND: C1.2, C2.2, C3.2, C4.2, C5.2, C6.2, C7.2, C8.2, C9.2, D2.1 (K), D3.1 (K), D4.1 (K), D5.1 (K), H1.1, H2.1, H3.1, IC1.2 (GND), J2.5 (GND), J2.6 (Shield), J3.2, J4.4, Q1.4, Q2.2 (S), R2.2, R4.2, SW1.2, SW2.2, U1.15 (GND), U2.1 (TEMP), U2.3 (GND), U2.9 (EPAD), U3.6 (GND)
unnamed: C6.1, R6.2, SW1.1
unnamed: C7.1, R11.2, SW2.1
unnamed: D1.2 (A), U2.7 (~CHRG)
unnamed: D1.1 (K), R1.2
unnamed: D2.2 (A), R12.1
unnamed: D3.2 (A), R13.1
unnamed: D4.2 (A), R14.1
unnamed: D5.2 (A), R15.1
unnamed: Q1.5, R9.2
unnamed: R2.1, U2.2 (PROG)
unnamed: R9.1, U3.2 (CS)
unnamed: Q1.6, Q1.7, U3.3 (OC)
unnamed: Q1.2, Q1.3, U3.1 (OD)
unnamed: C3.1, R3.2, U3.5 (VCC)

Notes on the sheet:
MCU BOOT CONFIG
CHARGING - TP4056
EXPANDERS
ESP12F - MCU
LDO - RT9080 3.3V
PROTECTION CIRCUIT
BUZZ_CTRL
MOUNTING HOLES
PHERIPHERALS

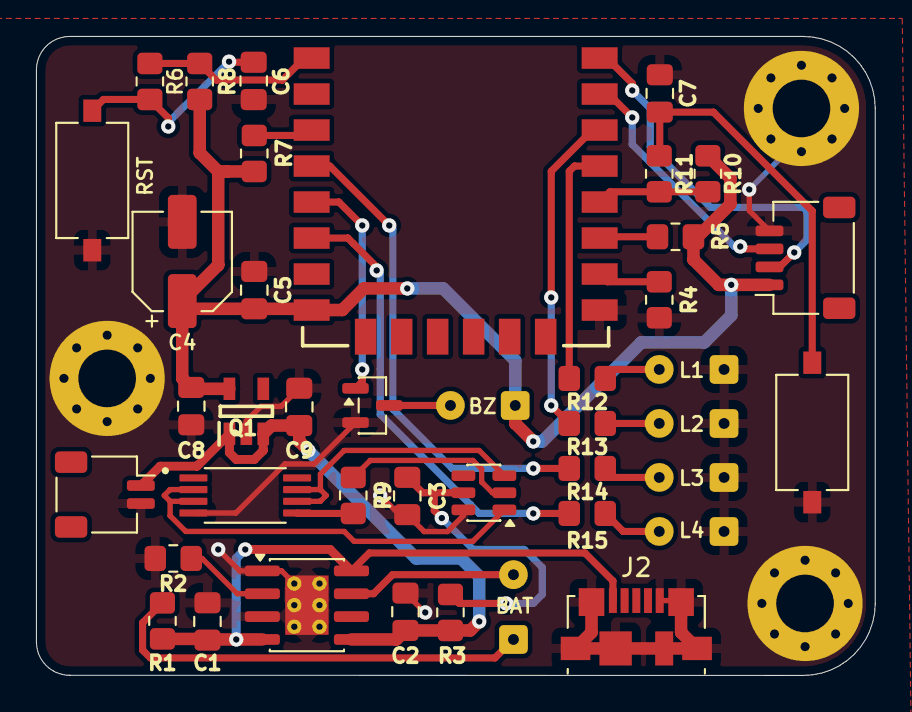
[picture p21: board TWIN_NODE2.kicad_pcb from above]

Board: 2 copper layers, 46.6 x 35.5 mm, 44 parts (0 on the bottom side), 31 nets.

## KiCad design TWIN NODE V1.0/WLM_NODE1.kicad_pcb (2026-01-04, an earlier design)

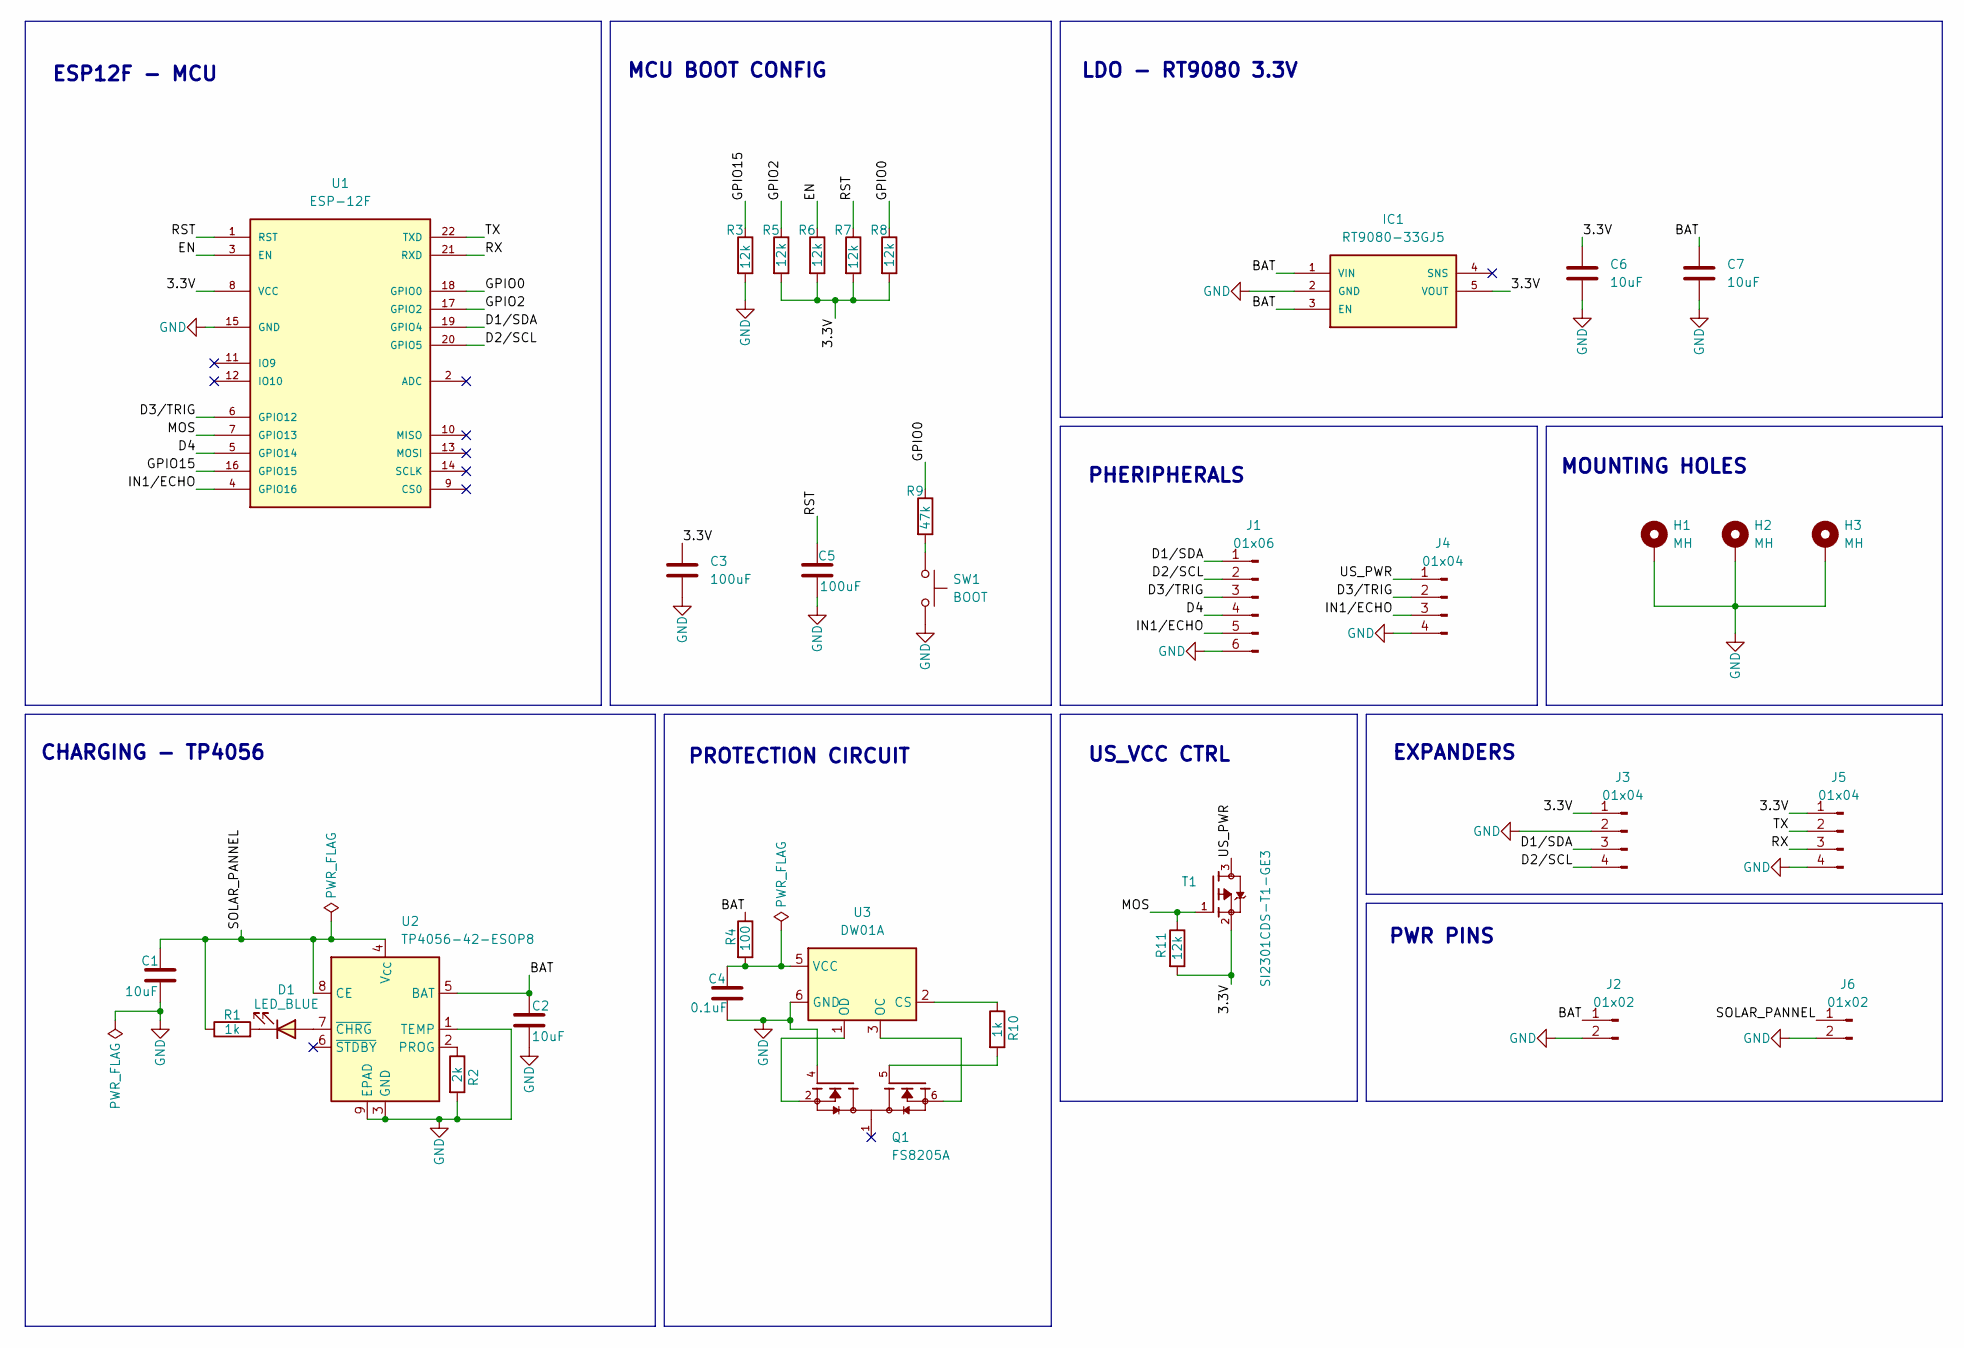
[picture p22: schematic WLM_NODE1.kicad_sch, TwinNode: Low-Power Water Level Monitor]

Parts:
C1, C2, C6, C7: 10uF; C_0805_2012Metric_Pad1.18x1.45mm_HandSolder
C3, C5: 100uF; C_0805_2012Metric_Pad1.18x1.45mm_HandSolder
C4: 0.1uF; C_0805_2012Metric_Pad1.18x1.45mm_HandSolder
D1: LED_BLUE; LED_0805_2012Metric_Pad1.15x1.40mm_HandSolder
H1, H2, H3: MH; MountingHole_3.2mm_M3_Pad_Via
IC1: RT9080-33GJ5; SOT94P280X100-5N
J1: 01x06; JST_SH_SM06B-SRSS-TB_1x06-1MP_P1.00mm_Horizontal
J2, J6: 01x02; JST_SH_SM02B-SRSS-TB_1x02-1MP_P1.00mm_Horizontal
J3, J5: 01x04; PinSocket_1x04_P2.54mm_Vertical
J4: 01x04; JST_SH_SM04B-SRSS-TB_1x04-1MP_P1.00mm_Horizontal
Q1: FS8205A; SOP65P640X120-8N; PARTREV 1.7
R1, R10: 1k; R_0805_2012Metric_Pad1.20x1.40mm_HandSolder
R2: 2k; R_0805_2012Metric_Pad1.20x1.40mm_HandSolder
R3, R5, R6, R7, R8, R11: 12k; R_0805_2012Metric_Pad1.20x1.40mm_HandSolder
R4: 100; R_0805_2012Metric_Pad1.20x1.40mm_HandSolder
R9: 47k; R_0805_2012Metric_Pad1.20x1.40mm_HandSolder
SW1: BOOT; SW_Tactile_SPST_NO_Straight_CK_PTS636Sx25SMTRLFS
T1: SI2301CDS-T1-GE3; SOT-23
U1: ESP-12F
U2: TP4056-42-ESOP8; SOIC-8-1EP_3.9x4.9mm_P1.27mm_EP2.41x3.3mm_ThermalVias
U3: DW01A; SOT-23-6

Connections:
/3.3V: C3.1, C6.1, IC1.5 (VOUT), J3.1, J5.1, R5.2, R6.2, R7.2, R8.2, R11.2, T1.2, U1.8 (VCC)
/BAT: C2.1, C7.1, IC1.1 (VIN), IC1.3 (EN), J2.1, R4.1, U2.5 (BAT); also elsewhere on the board
/D1/SDA: J1.1, J3.3, U1.19 (GPIO4)
/D2/SCL: J1.2, J3.4, U1.20 (GPIO5)
/D3/TRIG: J1.3, J4.2, U1.6 (GPIO12); also elsewhere on the board
/D4: J1.4, U1.5 (GPIO14)
/EN: R6.1, U1.3 (EN)
/GPIO0: R8.1, R9.1, U1.18 (GPIO0)
/GPIO2: R5.1, U1.17 (GPIO2)
/GPIO15: R3.1, U1.16 (GPIO15)
/IN1/ECHO: J1.5, J4.3, U1.4 (GPIO16); also elsewhere on the board
/MOS: R11.1, T1.1, U1.7 (GPIO13)
/RST: C5.1, R7.1, U1.1 (RST)
/RX: J5.3, U1.21 (RXD)
/SOLAR_PANNEL: C1.1, J6.1, R1.1, U2.4 (V_{CC}), U2.8 (CE); also elsewhere on the board
/TX: J5.2, U1.22 (TXD)
/US_PWR: J4.1, T1.3; also elsewhere on the board
GND: C1.2, C2.2, C3.2, C4.2, C5.2, C6.2, C7.2, H1.1, H2.1, H3.1, IC1.2 (GND), J1.6, J2.2, J3.2, J4.4, J5.4, J6.2, Q1.4, R2.2, R3.2, SW1.2, U1.15 (GND), U2.1 (TEMP), U2.3 (GND), U2.9 (EPAD), U3.6 (GND); also elsewhere on the board
unnamed: D1.2 (A), U2.7 (~CHRG)
unnamed: D1.1 (K), R1.2
unnamed: Q1.5, R10.2
unnamed: R9.2, SW1.1
unnamed: R2.1, U2.2 (PROG)
unnamed: R10.1, U3.2 (CS)
unnamed: Q1.6, Q1.7, U3.3 (OC)
unnamed: Q1.2, Q1.3, U3.1 (OD)
unnamed: C4.1, R4.2, U3.5 (VCC)

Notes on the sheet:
MCU BOOT CONFIG
LDO - RT9080 3.3V
US_VCC CTRL
ESP12F - MCU
PWR PINS
CHARGING - TP4056
PHERIPHERALS
EXPANDERS
MOUNTING HOLES
PROTECTION CIRCUIT

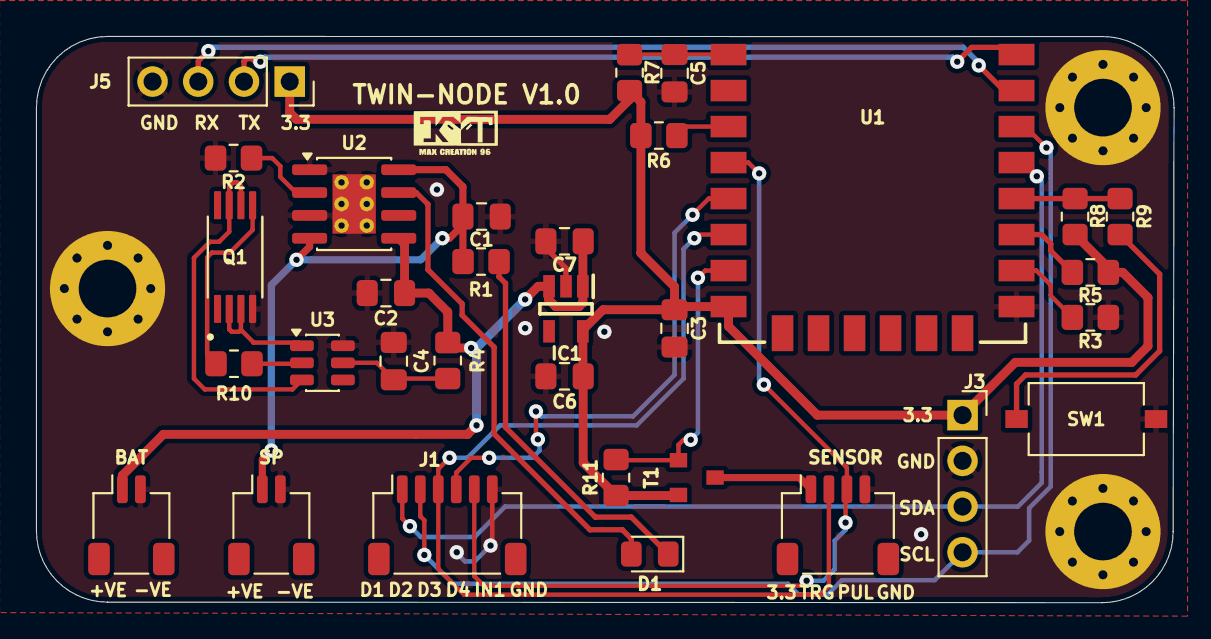
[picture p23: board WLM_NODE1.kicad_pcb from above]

Board: 2 copper layers, 63.2 x 31.5 mm, 35 parts (0 on the bottom side), 27 nets.

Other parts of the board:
BAT: 01x02; JST_SH_SM02B-SRSS-TB_1x02-1MP_P1.00mm_Horizontal
SENSOR: 01x04; JST_SH_SM04B-SRSS-TB_1x04-1MP_P1.00mm_Horizontal
SP: 01x02; JST_SH_SM02B-SRSS-TB_1x02-1MP_P1.00mm_Horizontal

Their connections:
/BAT: BAT.1; also elsewhere on the board
/D3/TRIG: SENSOR.2; also elsewhere on the board
/IN1/ECHO: SENSOR.3; also elsewhere on the board
/SOLAR_PANNEL: SP.1; also elsewhere on the board
/US_PWR: SENSOR.1; also elsewhere on the board
GND: BAT.2, SENSOR.4, SP.2; also elsewhere on the board

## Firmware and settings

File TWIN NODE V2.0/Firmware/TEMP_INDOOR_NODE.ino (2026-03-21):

/*
 * ============================================================
 *   💧 SMART WATER TANK MONITORING SYSTEM
 *      INDOOR NODE FIRMWARE — ESP8266 (ESP-NOW Receiver)
 * ============================================================
 *
 *  Author   : MAATHES THILAK K
 *  Version  : 1.0.0
 *  Board    : ESP8266 (NodeMCU / Wemos D1 Mini)
 *  Protocol : ESP-NOW (Connectionless)
 *  Created  : March 22, 2025
 *
 *  Description:
 *    This firmware runs on the INDOOR node of a smart water
 *    tank monitoring system. It:
 *      - Listens for ESP-NOW packets from the outdoor sensor node
 *      - Immediately sends an ACK back to the outdoor node
 *      - Computes water level % from received distance
 *      - Drives 4 LEDs to indicate tank fill level
 *      - Triggers a buzzer on FULL / CRITICAL LOW conditions
 *      - Detects outdoor node disconnection via timeout
 *      - Provides full debug info over Serial (115200 baud)
 *
 *  ⚠️  IMPORTANT BEFORE FLASHING:
 *    - Set OUTDOOR_NODE_MAC to the outdoor node's MAC address
 *    - Adjust TANK_HEIGHT_CM to your actual tank height
 *    - Verify all pin definitions for your PCB layout
 *
 * ============================================================
 */

#include <ESP8266WiFi.h>
#include <espnow.h>

// ============================================================
//  ⚙️  CONFIGURABLE PARAMETERS  — Edit these freely
// ============================================================

// --- Tank Physical Configuration ---
#define TANK_HEIGHT_CM        100     // Total empty tank height in cm
                                      // (distance from sensor to tank floor when empty)

// --- Communication Thresholds ---
#define DELTA_THRESHOLD_CM    3       // Minimum distance change (cm) considered significant
                                      // Matching the outdoor node's threshold

// --- Timing Configuration (milliseconds) ---
#define ACK_SEND_DELAY_MS     5       // Small delay before sending ACK (stabilise RF)
#define ACTIVE_CHECK_MS       5000    // Interval to refresh display when no new data arrives
#define DATA_TIMEOUT_MS       600000  // 10 minutes: warn if no packet received within this window

// --- Buzzer Behaviour ---
#define BUZZER_DURATION_MS    300     // Duration of each individual beep (ms)
#define BUZZER_GAP_MS         200     // Gap between beeps (ms)
#define BUZZER_FULL_BEEPS     3       // Number of beeps when tank is FULL
#define BUZZER_LOW_BEEPS      5       // Number of rapid beeps for CRITICAL LOW

// --- Water Level Alert Thresholds (%) ---
#define LEVEL_FULL_PCT        95      // Tank considered FULL above this %
#define LEVEL_CRITICAL_LOW_PCT 10     // Tank considered CRITICALLY LOW below this %

// --- LED Level Bands (%) ---
//   LED1 lights when level ≥ LED1_THRESHOLD
//   LED2 lights when level ≥ LED2_THRESHOLD  … and so on
#define LED1_THRESHOLD        5       // 0–25% band  (show LED1 even at very low level)
#define LED2_THRESHOLD        25      // 25–50% band
#define LED3_THRESHOLD        50      // 50–75% band
#define LED4_THRESHOLD        75      // 75–100% band

// ============================================================
//  📌  PIN DEFINITIONS  — Adjust for your wiring
// ============================================================

#define LED1_PIN      D1    // GPIO 5  — Level 0–25%
#define LED2_PIN      D2    // GPIO 4  — Level 25–50%
#define LED3_PIN      D5    // GPIO 14 — Level 50–75%
#define LED4_PIN      D6    // GPIO 12 — Level 75–100%
#define BUZZER_PIN    D7    // GPIO 13 — Active buzzer

// ============================================================
//  📡  OUTDOOR NODE MAC ADDRESS  — ⚠️ UPDATE THIS!
// ============================================================
//  Run the outdoor node once with Serial Monitor open.
//  It will print its MAC like:  Outdoor MAC: AA:BB:CC:DD:EE:FF
//  Replace the bytes below accordingly.

uint8_t OUTDOOR_NODE_MAC[6] = { 0xFF, 0xFF, 0xFF, 0xFF, 0xFF, 0xFF };
//                              ↑ Replace with actual outdoor node MAC

// ============================================================
//  📦  DATA STRUCTURES  (must match outdoor node exactly)
// ============================================================

typedef struct __attribute__((packed)) DataPacket {
  uint16_t distance;   // Measured distance in cm (median-filtered)
  uint8_t  nodeState;  // 0 = LOW_POWER mode, 1 = ACTIVE mode
  uint8_t  battery;    // Battery level % (0 if not implemented)
} DataPacket;

typedef struct __attribute__((packed)) AckPacket {
  uint8_t status;      // 1 = ACK OK
} AckPacket;

// ============================================================
//  🗃️  GLOBAL STATE
// ============================================================

volatile bool     g_newDataFlag    = false;   // Set in ISR-like callback, consumed in loop()
DataPacket        g_latestPacket   = {0, 0, 0};
uint16_t          g_lastDistance   = 0;       // Last displayed/processed distance
unsigned long     g_lastDataMillis = 0;       // Timestamp of last received packet
unsigned long     g_lastRefreshMs  = 0;       // Timestamp of last LED refresh
bool              g_tankWasFull    = false;   // Latched flag — prevents repeat alerts
bool              g_tankWasLow     = false;   // Latched flag — prevents repeat alerts
bool              g_timeoutWarned  = false;   // Has timeout warning fired this cycle?
uint32_t          g_packetCount    = 0;       // Total packets received since boot

// ============================================================
//  🔔  ESP-NOW RECEIVE CALLBACK
//  Called automatically when a packet arrives.
//  Keep it short — just store data + send ACK.
// ============================================================

void ICACHE_RAM_ATTR onDataReceived(uint8_t *senderMAC, uint8_t *rawData, uint8_t len) {

  if (len != sizeof(DataPacket)) {
    Serial.printf("[WARN] Unexpected packet size: %d bytes (expected %d)\n",
                  len, sizeof(DataPacket));
    return;
  }

  // Copy safely into global struct
  memcpy(&g_latestPacket, rawData, sizeof(DataPacket));
  g_newDataFlag    = true;
  g_lastDataMillis = millis();
  g_packetCount++;

  // ── Send ACK immediately ──────────────────────────────────
  delay(ACK_SEND_DELAY_MS);
  AckPacket ack;
  ack.status = 1;
  esp_now_send(senderMAC, (uint8_t *)&ack, sizeof(AckPacket));
  // ─────────────────────────────────────────────────────────

  Serial.printf("[RX #%lu] Dist=%d cm | State=%s | Batt=%d%%\n",
    (unsigned long)g_packetCount,
    g_latestPacket.distance,
    g_latestPacket.nodeState == 1 ? "ACTIVE" : "LOW_POWER",
    g_latestPacket.battery
  );
  Serial.println("[TX] ACK sent to outdoor node");
}

// ============================================================
//  💧  WATER LEVEL CALCULATION
//  Returns 0–100 (percentage fill)
// ============================================================

uint8_t calcWaterLevel(uint16_t distanceCm) {
  if (distanceCm == 0)                    return 100; // Sensor at bottom = full
  if (distanceCm >= TANK_HEIGHT_CM)       return 0;   // Sensor max range = empty

  int32_t filled = (int32_t)TANK_HEIGHT_CM - (int32_t)distanceCm;
  uint8_t level  = (uint8_t)((filled * 100L) / TANK_HEIGHT_CM);
  return (uint8_t)constrain(level, 0, 100);
}

// ============================================================
//  💡  LED CONTROL
// ============================================================

void updateLEDs(uint8_t levelPct) {
  digitalWrite(LED1_PIN, (levelPct >= LED1_THRESHOLD) ? HIGH : LOW);
  digitalWrite(LED2_PIN, (levelPct >= LED2_THRESHOLD) ? HIGH : LOW);
  digitalWrite(LED3_PIN, (levelPct >= LED3_THRESHOLD) ? HIGH : LOW);
  digitalWrite(LED4_PIN, (levelPct >= LED4_THRESHOLD) ? HIGH : LOW);
}

void allLEDsOff() {
  digitalWrite(LED1_PIN, LOW);
  digitalWrite(LED2_PIN, LOW);
  digitalWrite(LED3_PIN, LOW);
  digitalWrite(LED4_PIN, LOW);
}

void allLEDsOn() {
  digitalWrite(LED1_PIN, HIGH);
  digitalWrite(LED2_PIN, HIGH);
  digitalWrite(LED3_PIN, HIGH);
  digitalWrite(LED4_PIN, HIGH);
}

// Blink all LEDs together — used for startup animation & warnings
void blinkAllLEDs(int times, int onMs, int offMs) {
  for (int i = 0; i < times; i++) {
    allLEDsOn();
    delay(onMs);
    allLEDsOff();
    if (i < times - 1) delay(offMs);
  }
}

// Cascade blink (LED1 → LED4 → LED1) — startup flair
void cascadeLEDs(int sweeps, int stepMs) {
  for (int s = 0; s < sweeps; s++) {
    uint8_t pins[4] = { LED1_PIN, LED2_PIN, LED3_PIN, LED4_PIN };
    // Up sweep
    for (int i = 0; i < 4; i++) {
      allLEDsOff();
      digitalWrite(pins[i], HIGH);
      delay(stepMs);
    }
    // Down sweep
    for (int i = 2; i >= 0; i--) {
      allLEDsOff();
      digitalWrite(pins[i], HIGH);
      delay(stepMs);
    }
  }
  allLEDsOff();
}

// ============================================================
//  🔊  BUZZER CONTROL
// ============================================================

void beep(int count, int onMs, int offMs) {
  for (int i = 0; i < count; i++) {
    digitalWrite(BUZZER_PIN, HIGH);
    delay(onMs);
    digitalWrite(BUZZER_PIN, LOW);
    if (i < count - 1) delay(offMs);
  }
}

// ============================================================
//  🚨  ALERT LOGIC  (called once per new data packet)
//  Uses latched flags to fire alert ONCE per transition,
//  not on every packet while condition persists.
// ============================================================

void checkAndTriggerAlerts(uint8_t levelPct) {

  // ── FULL TANK ─────────────────────────────────────────────
  if (levelPct >= LEVEL_FULL_PCT) {
    if (!g_tankWasFull) {
      g_tankWasFull = true;
      Serial.println("╔══════════════════════════════════╗");
      Serial.println("║  🟢  ALERT: TANK IS FULL (≥95%)  ║");
      Serial.println("╚══════════════════════════════════╝");
      // Three distinct beeps: tank is full
      beep(BUZZER_FULL_BEEPS, BUZZER_DURATION_MS, BUZZER_GAP_MS);
    }
  } else {
    g_tankWasFull = false;  // Reset latch once level drops
  }

  // ── CRITICAL LOW ─────────────────────────────────────────
  if (levelPct <= LEVEL_CRITICAL_LOW_PCT) {
    if (!g_tankWasLow) {
      g_tankWasLow = true;
      Serial.println("╔═══════════════════════════════════════════╗");
      Serial.println("║  🔴  ALERT: CRITICAL LOW WATER (≤10%)    ║");
      Serial.println("╚═══════════════════════════════════════════╝");
      // Rapid short beeps: urgent
      beep(BUZZER_LOW_BEEPS, 100, 100);
    }
  } else {
    g_tankWasLow = false;
  }
}

// ============================================================
//  📋  SERIAL STATUS DISPLAY
// ============================================================

void printStatus(uint16_t distanceCm, uint8_t levelPct) {
  char levelBar[22];  // 20-char bar + \0
  int  filled = (levelPct * 20) / 100;
  for (int i = 0; i < 20; i++) levelBar[i] = (i < filled) ? '#' : '-';
  levelBar[20] = '\0';

  Serial.println();
  Serial.println("┌─────────────────────────────────┐");
  Serial.printf ("│  Distance  : %4d cm             │\n", distanceCm);
  Serial.printf ("│  Level     : %3d%%               │\n", levelPct);
  Serial.printf ("│  [%s]  │\n", levelBar);
  Serial.printf ("│  LEDs      : %s%s%s%s           │\n",
    (levelPct >= LED1_THRESHOLD) ? "1 " : "_ ",
    (levelPct >= LED2_THRESHOLD) ? "2 " : "_ ",
    (levelPct >= LED3_THRESHOLD) ? "3 " : "_ ",
    (levelPct >= LED4_THRESHOLD) ? "4 " : "_ "
  );
  Serial.printf ("│  Packets   : %-6lu               │\n",
    (unsigned long)g_packetCount);
  Serial.println("└─────────────────────────────────┘");
}

// ============================================================
//  🔧  HELPER: Print local MAC on Serial
// ============================================================

void printMACAddress() {
  Serial.print("  Indoor Node MAC : ");
  Serial.println(WiFi.macAddress());
}

// ============================================================
//  ⚡  SETUP
// ============================================================

void setup() {
  Serial.begin(115200);
  delay(200);

  Serial.println();
  Serial.println("╔══════════════════════════════════════════╗");
  Serial.println("║   💧 WATER TANK MONITOR — INDOOR NODE   ║");
  Serial.println("║   ESP8266  |  ESP-NOW Receiver  v1.0    ║");
  Serial.println("╚══════════════════════════════════════════╝");

  // ── GPIO Init ───────────────────────────────────────────
  pinMode(LED1_PIN,   OUTPUT);
  pinMode(LED2_PIN,   OUTPUT);
  pinMode(LED3_PIN,   OUTPUT);
  pinMode(LED4_PIN,   OUTPUT);
  pinMode(BUZZER_PIN, OUTPUT);

  allLEDsOff();
  digitalWrite(BUZZER_PIN, LOW);

  // ── Startup Sequence ────────────────────────────────────
  cascadeLEDs(2, 80);              // Sweep animation
  beep(1, 150, 0);                 // Single boot beep
  delay(200);

  // ── WiFi (Station mode, disconnected — required for ESP-NOW) ──
  WiFi.mode(WIFI_STA);
  WiFi.disconnect();
  delay(100);

  Serial.println();
  Serial.println("  [CONFIG]");
  printMACAddress();
  Serial.printf ("  Tank Height     : %d cm\n",  TANK_HEIGHT_CM);
  Serial.printf ("  Delta Threshold : %d cm\n",  DELTA_THRESHOLD_CM);
  Serial.printf ("  ACK Delay       : %d ms\n",  ACK_SEND_DELAY_MS);
  Serial.printf ("  Refresh Interval: %d ms\n",  ACTIVE_CHECK_MS);
  Serial.printf ("  Timeout Warning : %d ms\n",  DATA_TIMEOUT_MS);
  Serial.printf ("  Full alert at   : %d%%\n",   LEVEL_FULL_PCT);
  Serial.printf ("  Low alert at    : %d%%\n",   LEVEL_CRITICAL_LOW_PCT);

  // ── ESP-NOW Init ─────────────────────────────────────────
  if (esp_now_init() != 0) {
    Serial.println("\n  [ERROR] ESP-NOW initialization FAILED!");
    Serial.println("  Entering fault loop — check board & power.");
    while (true) {
      blinkAllLEDs(3, 80, 80);
      delay(600);
    }
  }

  esp_now_set_self_role(ESP_NOW_ROLE_COMBO);
  esp_now_register_recv_cb(onDataReceived);

  // Register outdoor node as a peer (required to send ACK back)
  if (esp_now_add_peer(OUTDOOR_NODE_MAC, ESP_NOW_ROLE_COMBO, 1, NULL, 0) != 0) {
    Serial.println("\n  [WARN] Could not register outdoor node peer.");
    Serial.println("  Verify OUTDOOR_NODE_MAC is correct.");
    // Non-fatal — receive still works; ACK will fail
  }

  g_lastDataMillis = millis();
  g_lastRefreshMs  = millis();

  Serial.println("\n  [OK]  ESP-NOW initialised. Listening...");
  Serial.println("══════════════════════════════════════════");

  // Show "waiting" state on LEDs
  allLEDsOff();
  blinkAllLEDs(1, 300, 0);  // Single blink = ready
}

// ============================================================
//  🔁  MAIN LOOP
// ============================================================

void loop() {
  unsigned long now = millis();

  // ── 1. Process incoming data ──────────────────────────────
  if (g_newDataFlag) {
    g_newDataFlag = false;
    g_timeoutWarned = false;     // Connection resumed — reset timeout flag

    uint16_t dist  = g_latestPacket.distance;
    uint8_t  level = calcWaterLevel(dist);

    updateLEDs(level);
    checkAndTriggerAlerts(level);
    printStatus(dist, level);

    g_lastDistance  = dist;
    g_lastRefreshMs = now;
  }

  // ── 2. Periodic LED refresh ───────────────────────────────
  //    (Keeps LEDs correct even without new data)
  if (now - g_lastRefreshMs >= ACTIVE_CHECK_MS) {
    g_lastRefreshMs = now;
    if (g_lastDistance > 0) {
      uint8_t level = calcWaterLevel(g_lastDistance);
      updateLEDs(level);
      Serial.printf("[Refresh] Level: %3d%% | Distance: %d cm\n",
                    level, g_lastDistance);
    }
  }

  // ── 3. Outdoor node timeout detection ─────────────────────
  //    If no packet for DATA_TIMEOUT_MS → warn once per cycle
  if ((now - g_lastDataMillis >= DATA_TIMEOUT_MS) && !g_timeoutWarned) {
    g_timeoutWarned = true;
    unsigned long minsSince = (now - g_lastDataMillis) / 60000UL;

    Serial.println();
    Serial.println("╔══════════════════════════════════════════╗");
    Serial.printf ("║  ⚠️  NO DATA for %3lu min — node offline?  ║\n",
                    minsSince);
    Serial.println("╚══════════════════════════════════════════╝");

    // Visual warning: slow blink all LEDs once
    blinkAllLEDs(2, 400, 300);

    // Restore level display after blink
    if (g_lastDistance > 0) {
      updateLEDs(calcWaterLevel(g_lastDistance));
    }
  }

  // ── 4. Yield to system (ESP8266 watchdog) ─────────────────
  yield();
}

// ============================================================
//  END OF FILE
// ============================================================

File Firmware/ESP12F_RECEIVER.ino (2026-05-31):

#include <Arduino.h>
#include <ESP8266WiFi.h>
#include <espnow.h>

extern "C" {
  #include <user_interface.h>
}
//ESP12F MAC Address: 24:4C:AB:6C:E4:F8 - LION PCB TRANSMITTER
// --------------------------------------------------
// ESP32 TRANSMITTER MAC ADDRESS
// TX MAC Address: 24:6F:28:3A:B5:68
// --------------------------------------------------
uint8_t transmitterMacAddress[] = {0x24, 0x4C, 0xAB, 0x6C, 0xE4, 0xF8};

// --------------------------------------------------
// PIN CONFIGURATION - ESP12F RECEIVER
// --------------------------------------------------
#define LED_LOW_PIN     12   // GPIO12 - LOW level LED
#define LED_MED_PIN     16   // GPIO16 - MEDIUM level LED
#define LED_HIGH_PIN    5    // GPIO5  - HIGH level LED
#define LED_FULL_PIN    4    // GPIO4  - FULL level LED

#define BUZZER_PIN      14   // GPIO14 - Buzzer

// --------------------------------------------------
// ESP-NOW CHANNEL
// Must match transmitter channel
// --------------------------------------------------
#define ESPNOW_CHANNEL  1

// --------------------------------------------------
// DATA STRUCTURE
// Must match ESP32 transmitter structure
// --------------------------------------------------
typedef struct struct_message {
  float distanceCm;
  int waterPercent;
  int level;
  bool tankFull;
  bool tankEmpty;
} struct_message;

struct_message receivedData;

// --------------------------------------------------
// PRINT MAC ADDRESS
// --------------------------------------------------
void printMacAddress(uint8_t *mac) {
  for (int i = 0; i < 6; i++) {
    if (mac[i] < 16) Serial.print("0");
    Serial.print(mac[i], HEX);
    if (i < 5) Serial.print(":");
  }
}

// --------------------------------------------------
// CHECK KNOWN TRANSMITTER
// --------------------------------------------------
bool isFromKnownTransmitter(uint8_t *mac) {
  for (int i = 0; i < 6; i++) {
    if (mac[i] != transmitterMacAddress[i]) {
      return false;
    }
  }
  return true;
}

// --------------------------------------------------
// TURN OFF ALL LEDS
// --------------------------------------------------
void allLedsOff() {
  digitalWrite(LED_LOW_PIN, LOW);
  digitalWrite(LED_MED_PIN, LOW);
  digitalWrite(LED_HIGH_PIN, LOW);
  digitalWrite(LED_FULL_PIN, LOW);
}

// --------------------------------------------------
// UPDATE 4 LEVEL LED STATUS
// --------------------------------------------------
void updateLevelLEDs(int waterPercent) {
  allLedsOff();

  if (waterPercent < 0) {
    Serial.println("Invalid water percentage. LEDs OFF.");
    return;
  }

  if (waterPercent <= 25) {
    digitalWrite(LED_LOW_PIN, HIGH);
    Serial.println("LED Status: LOW");
  }
  else if (waterPercent <= 50) {
    digitalWrite(LED_MED_PIN, HIGH);
    Serial.println("LED Status: MEDIUM");
  }
  else if (waterPercent <= 80) {
    digitalWrite(LED_HIGH_PIN, HIGH);
    Serial.println("LED Status: HIGH");
  }
  else {
    digitalWrite(LED_FULL_PIN, HIGH);
    Serial.println("LED Status: FULL");
  }
}

// --------------------------------------------------
// BUZZER ONLY DURING FULL LEVEL
// --------------------------------------------------
void updateBuzzer(int waterPercent) {
  if (waterPercent > 80) {
    Serial.println("BUZZER: FULL alert");

    digitalWrite(BUZZER_PIN, HIGH);
    delay(1000);
    digitalWrite(BUZZER_PIN, LOW);
  }
  else {
    digitalWrite(BUZZER_PIN, LOW);
  }
}

// --------------------------------------------------
// ESP-NOW RECEIVE CALLBACK - ESP8266 FORMAT
// --------------------------------------------------
void onDataReceived(uint8_t *mac, uint8_t *incomingData, uint8_t len) {
  Serial.println();
  Serial.println("Data Received!");

  Serial.print("Sender MAC: ");
  printMacAddress(mac);
  Serial.println();

  if (!isFromKnownTransmitter(mac)) {
    Serial.println("Unknown transmitter. Data ignored.");
    return;
  }

  if (len != sizeof(receivedData)) {
    Serial.println("Data size mismatch!");
    Serial.print("Received size: ");
    Serial.println(len);
    Serial.print("Expected size: ");
    Serial.println(sizeof(receivedData));
    return;
  }

  memcpy(&receivedData, incomingData, sizeof(receivedData));

  Serial.println("------ Tank Data ------");

  Serial.print("Distance: ");
  Serial.print(receivedData.distanceCm);
  Serial.println(" cm");

  Serial.print("Water Percentage: ");
  Serial.print(receivedData.waterPercent);
  Serial.println(" %");

  Serial.print("Received Level: ");
  Serial.println(receivedData.level);

  Serial.print("Tank Full: ");
  Serial.println(receivedData.tankFull ? "YES" : "NO");

  Serial.print("Tank Empty: ");
  Serial.println(receivedData.tankEmpty ? "YES" : "NO");

  Serial.println("-----------------------");

  updateLevelLEDs(receivedData.waterPercent);
  updateBuzzer(receivedData.waterPercent);
}

// --------------------------------------------------
// SETUP
// --------------------------------------------------
void setup() {
  Serial.begin(115200);
  delay(1000);

  Serial.println();
  Serial.println("ESP12F Indoor Receiver Node Started");

  pinMode(LED_LOW_PIN, OUTPUT);
  pinMode(LED_MED_PIN, OUTPUT);
  pinMode(LED_HIGH_PIN, OUTPUT);
  pinMode(LED_FULL_PIN, OUTPUT);
  pinMode(BUZZER_PIN, OUTPUT);

  allLedsOff();
  digitalWrite(BUZZER_PIN, LOW);

  WiFi.mode(WIFI_STA);
  WiFi.disconnect();

  wifi_set_channel(ESPNOW_CHANNEL);

  Serial.print("Receiver ESP12F MAC Address: ");
  Serial.println(WiFi.macAddress());

  Serial.print("Expected Transmitter MAC: ");
  printMacAddress(transmitterMacAddress);
  Serial.println();

  Serial.print("Receiver Struct Size: ");
  Serial.println(sizeof(receivedData));

  if (esp_now_init() != 0) {
    Serial.println("ESP-NOW Init Failed!");
    return;
  }

  esp_now_set_self_role(ESP_NOW_ROLE_SLAVE);
  esp_now_register_recv_cb(onDataReceived);

  Serial.println("ESP-NOW Receiver Ready...");
}

// --------------------------------------------------
// LOOP
// --------------------------------------------------
void loop() {
  // Nothing needed here.
  // Data is handled inside onDataReceived().
}

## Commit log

2026-01-04 Add TWIN NODE V1.0 project files
    [WLM_NODE1-B_Cu.gbr, WLM_NODE1-B_Mask.gbr, WLM_NODE1-B_Paste.gbr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]
2026-01-04 Reorganize project files into TWIN NODE V1.0 folder
    [WLM_NODE1-B_Cu.gbr, WLM_NODE1-B_Mask.gbr, WLM_NODE1-B_Paste.gbr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]
2026-01-04 Add TWIN NODE V2.0 hardware design files
    [TWIN_NODE-B_Cu.gbr, TWIN_NODE-B_Mask.gbr, TWIN_NODE-B_Paste.gbr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]
2026-01-04 Remove TWIN NODE V2.0 files
    [TWIN_NODE-B_Cu.gbr, TWIN_NODE-B_Mask.gbr, TWIN_NODE-B_Paste.gbr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]
2026-01-04 Remove TWIN NODE V1.0 files
    [WLM_NODE1-B_Cu.gbr, WLM_NODE1-B_Mask.gbr, WLM_NODE1-B_Paste.gbr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]
